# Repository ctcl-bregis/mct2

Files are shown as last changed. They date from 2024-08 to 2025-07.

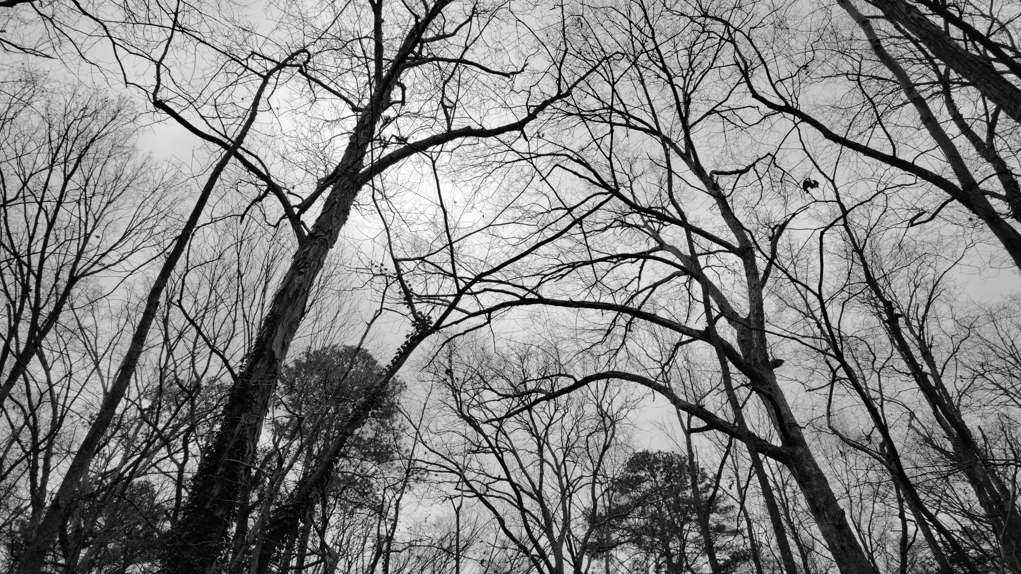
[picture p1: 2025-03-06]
media/background/mct2_midlo_1_1080p.png

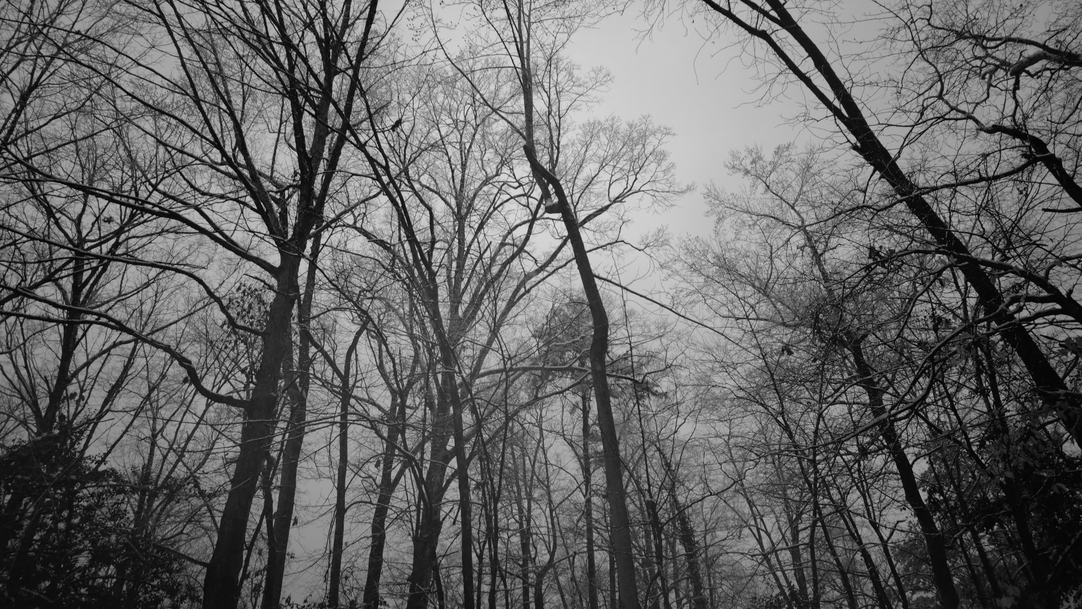
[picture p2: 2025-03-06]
media/background/mct2_midlo_1_v2_1080p.png

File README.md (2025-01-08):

<div>
  MediaCow Touch 2
</div>

# MediaCow Touch 2
MediaCow Touch 2 "Paris" is the successor to MediaCow Touch (1) "Nashville" which is a DIY portable tablet computer.

This repository has all of the hardware designs and some software for the project.

See [MediaCow Touch 2 page](https://ctcl.lgbt/projects/mct2/) for more information.

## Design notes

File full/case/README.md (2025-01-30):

This directory is to have design files for the case using the DFRobot 11.6 Inch 1920x1080 FHD eDP Touch Display (FIT0955)

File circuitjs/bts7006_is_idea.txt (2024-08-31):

$ 1 0.000005 10.20027730826997 50 5 50 5e-11
r 880 480 880 560 0 1200
g 880 560 880 576 0 0
R 848 400 848 304 0 0 40 20 0 0 0.5
r 608 480 608 560 0 100000
g 608 560 608 576 0 0
r 784 480 880 480 0 470000
c 688 480 688 560 0 2.2e-10 3.3878214977944507 0
g 688 560 688 576 0 0
b 309 415 658 869 0
b 808 293 949 456 0
w 688 480 608 480 0
x 311 408 338 411 4 12 MCU
x 807 285 891 288 4 12 BTS7006-1EPP
167 448 480 480 480 1024 12
w 608 480 544 480 0
R 544 832 592 832 0 0 40 3.3 0 0 0.5
419 320 480 416 480 1024 12
O 688 480 688 416 1 0
34 MMSZ5227B 0 1.0000000000000001e-7 24 11.402862559935903 3.6 0.1
z 784 560 784 480 2 MMSZ5227B
g 784 560 784 576 0 0
x 809 508 826 511 4 24 R
x 826 513 851 516 4 12 ADC
x 891 548 908 551 4 24 R
x 908 553 948 556 4 12 SENSE
x 309 352 355 355 4 24 Idea
w 784 480 688 480 0
i 912 336 912 400 0 0.045
g 912 336 912 320 0 0
S 880 480 880 400 0 0 false 0 2
w 896 400 912 400 0
w 864 400 848 400 0
o 3 128 0 4099 20 0.0001953125 0 2 3 3
o 0 128 0 4099 160 0.1 1 2 0 3
38 2 F1 0 0 48 -1 Voltage
38 26 F1 0 0 0.045 -1 Current

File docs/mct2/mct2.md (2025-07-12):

**Disclaimer**: Anything on this page and other pages related to this project is preliminary data and may change at any moment. Much of the following pages are a work in progress and may be incomplete.

## Overview
MediaCow Touch 2 is a tablet computer project that focuses on security, privacy, transparency and repairability. The project started in March 2021 while active development stared in June 2024.

In March 2025, development of a variant, MediaCow Touch 2 Lite, started in order to have a version of the project that can be completed in a shorter time frame.

### Specifications

Specifications for MediaCow Touch 2 "Paris" and MediaCow Touch 2 Lite "Curitiba" are listed below.

| Specification | MediaCow Touch 2 "Paris"  | MediaCow Touch 2 Lite "Curitiba"  |
| --- | --- | --- |
| SoC | Intel N100/N305 | Intel N100 |
| Memoryy | 8GB-16GB LPDDR5 | 8GB LPDDR5 |
| Storage | Configurable | Configurable |
| Display | 14" 1920x1200 Innolux AAS | 14" 1920x1200 Innolux AAS |
| Camera | TBD | TBD |
| Audio | TBD | IDT 92HD95 HD Audio CODEC |
| Embedded Controller | Sunplus/Tibbo SP7021 | STMicroelctronics STM32L071V8Tx |
| Battery | TBD | TBD |
| Dimensions | TBD | TBD |
| Weight | TBD | TBD |

## Naming
In 2025, MediaCow Touch 2 was split into two projects: MediaCow Touch 2 and MediaCow Touch 2 Lite. 

MediaCow Touch 2 "Paris" is refered to as the "Full" version and has all of the features introduced during development in 2024 including the SP7021 as the embedded controller, the side-mounted display and modular connectors.

MediaCow Touch 2 Lite "Curitiba" is the version of the project introduced in 2025 that leaves out many features to decrease development time and cost.

## Documentation
The pages are currently under a rewrite due to the introduction of MediaCow Touch 2 Lite so much of it is currently unavailable.

The following link to specific parts of the documentation:

{{button|page=/projects/mct2/connectivity/}}
{{button|page=/projects/mct2/display/}}
{{button|page=/projects/mct2/pcb/}}

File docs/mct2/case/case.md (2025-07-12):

## Material and Fabrication
MediaCow Touch 2's case is to be constructed from white PET(G) plastic as part of the theme.

Fortunately, the case's parts can be 3D printed whole as the total dimensions are within the 350x350mm bounds of a 3D printer available at a local makerspace.

## Design
The case is designed in OpenSCAD.

The case is split into three parts: the base, the display mount and the display cover. These parts are bolted together at four to six points. 

## Parts
The case is to be split into three parts: the **base**, the **display mount** and the **display cover**.

### Display Mount
The display mount is a tray-like structure that holds the display in place. The structure is made up of a single rectangle that is surrounded by walls.

The display mount was inspired by the System Cover Design Guidance section of the Innolux N156HGE and N140JCN-GS9 datasheet and various laptops that use a similar design such as the ThinkPad X240.

The display is held in place using double-sided tape that also acts as a spacer as the thickness of the display is wider at the LCD driver PCB area.

### Display Cover
The display cover is a thin layer that covers the outside edges of the display, acting as a screen bezel. 

### Base
The base component consists of the walls, PCB mounting points, connector cutouts and mounting points for connectors. It defines the structure of the device.

#### Side-mounted display mount
**Not present on MediaCow Touch 2 Lite**

The small touchscreen display on the side of the case is to be attached to the Side-Mounted Display PCB that contains the FPGA-based RGB-MIPI video bridge. The PCB is to be bolted at two or more points to mounting posts.

#### Keypad
**Not present on MediaCow Touch 2 Lite**

The keypad board, providing twelve tactile button switches. 

#### Buttons
**Only present on MediaCow Touch 2 Lite**

On MediaCow Touch 2 Lite, the buttons are to be mounted on the PCB with cutouts in the the case for the button caps.

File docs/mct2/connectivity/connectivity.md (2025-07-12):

## Physical Connectivity

MediaCow Touch 2 has the following physical connectivity:
- 2x USB Type-C with Power Delivery sink/source up to 20v, DP alternate mode and USB 3.2
- 2x USB 3.2 Type-A
- 1x RJ-45 Ethernet, provided by internal M.2 module
- 1x Full-size HDMI
- 1x 3.5mm headphone audio out
- 1x 3.5mm microphone audio in

MediaCow Touch 2 Lite has the following physical connectivity:
- 2x USB Type-C with Power Delivery sink/source up to 20v, DP alternate mode and USB 3.2
- 2x USB 3.2 Type-A
- 1x Full-size HDMI
- 1x 3.5mm headphone audio out
- 1x 3.5mm microphone audio in

### Audio

#### MediaCow Touch 2 "Paris"
**TBD**

#### MediaCow Touch 2 Lite "Curitiba"
MediaCow Touch 2 Lite "Curitiba" uses an HD Audio CODEC, making use of the HD Audio interface directly. Currently, the CODEC being used is the Tempo 92HD95. 

## Internal Connectivity
**TODO**: move all of this to PCB design pages

### TCP Ports
On MediaCow Touch 2 and MediaCow Touch 2 Lite, both TCP ports are used for USB Type-C providing USB 3.2, Power Delivery up to 20v and DisplayPort alternate mode.

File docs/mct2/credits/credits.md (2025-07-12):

## Software Used
Open Source software has been used whenever possible. 

### CAD and EDA

#### KiCAD
KiCAD is used to draw electrical schematics and design the carrier board PCB.

#### LibreCAD
LibreCAD was used for the first time on August 6 to record measurements of the battery pack that is used in the device.

Its use, however, was brief and was eventually replaced by QCAD.

#### QCAD
Starting January 1, 2025, QCAD is used for technical, mechanical drawings, taking place of draw.io for such task. Its use is still limited.

#### OpenSCAD 
OpenSCAD is used extensively for 3D design.

#### FreeCAD
FreeCAD was very briefly used for case design. No part of the current case design was done in FreeCAD.

### Planning and Documentation

#### draw.io/diagrams.net
draw.io is extensively used for rough physical diagrams and electrical block diagrams. The draw.io desktop client command line features are used by StaticSite to render .drawio files.

#### Git and GitHub
The MediaCow Touch 2 hardware design and software files are hosted on GitHub for anyone to see while having the ability to easily sync progress across devices in cases where I have to go somewhere.

#### StaticSite
StaticSite is used to generate this website starting December 31, 2024. Prior to this, website backends called "ctclsite-rust" and "ctclsite-python" were used to serve website content.

#### Discord
Using a chat service in as a way to dump ideas into categories has returned from MediaCow Touch 1 where I used a self-hosted Rocket.Chat instance for that purpose. This time I used a private "server" on Discord to brainstorm ideas. At the conclusion of the project, I would make a public release of the channel logs. 

#### MediaWiki
A self-hosted MediaWiki instance is used for personal documentation. It's role in MediaCow Touch 2, however, is very limited. 

#### STM32CubeMX
STM32CubeMX was used to select the microcontroller used as the embedded controller (SMEC) and plan its pinout until the switch to the SP7021 as the embedded controller.

#### Sourcegraph Cody + Claude 3.5/Claude 3.7/GPT-4o
Sourcegraph Cody has found extensive use in many of my projects, including this one, starting in late 2024. It is used for sentence completion in documentation and code completion in software and firmware development. Some case design with OpenSCAD was assisted by AI.

#### CircuitJS
[CircuitJS](https://falstad.com/circuit/) has been used to test ideas such as using Schottky diodes on the power inputs of SPI flash memory and connecting the IS pin of the Infineon BTS7006 to a microcontroller.

### Software Development
This software was used to develop software for the project.

#### VSCodium
VSCodium is used as the main editor for any software project, including this website. Content like these pages are written using VSCodium.

The 'Open Remote - SSH' extension played a crucial role during development as it let me edit files on the desktop PC from anywhwere like I am using VSCodium on that system.

## Hardware Used
Hardware used for development since May 2024:

**Format: Codename - Motherboard**

### Development Hardware

- LattePanda Mu N100
  - Experimentation
  - Communications
  - Research

### Workstations

- ASRock B550M Pro4
  - Circuit and device design
  - Documentation
  - Software development
  - Research
  - Communications
- HP ZBook Studio G3 15
  - Circuit and device design
  - Documentation
  - Software development
  - Research
  - Communications
- Lenovo ThinkPad T450s
  - Device design
  - Documentation
  - Research
- Lenovo ThinkPad T430s
  - Communications
  - Circuit design
  - Documentation
  - Research
  - Planning
- Apple iPhone XR (A1984)
  - Social media promotion
  - Research
  - Communications
- ASUS Zenfone 9 (AI2202)
  - Documentation
  - Communications
  - Research
  - Remote internet access
- Valve Steam Deck OLED (1030)
  - Communications
  - Documentation
  - Research
  - Planning
- Samsung Galaxy S7 WW (SM-G930F)
  - Communications
  - Research
  - Planning
- MediaCow Touch 1 (Banana Pi BPI-M64)
  - Communications
  - Media playback

Non-CTCL Hardware:
- Dell OptiPlex 7460 AIO - Brightpoint Community College MIDLRTC19928
  - Datasheet viewing

### Servers

- SVCS1 (pre-2025) - HP ProLiant BL460c G8
  - File storage host (Nextcloud)
  - Planning (MediaWiki)
  - DNS server
- SVCS1 (2025) - Supermicro X8DAi
  - DNS server
- WBSD1 - Supermicro X8SIE
  - File storage
- ROUTER1 - Supermicro X8SIE
  - Router
  - Remote access host

### Other

- Texas Instruments TI-Nspire CX
  - Formula calculation
- Flipper Zero FZ.1
  - Device debugging

## Locations

MediaCow Touch 2 was developed in the following locations:

- Atlantic Beach, North Carolina, United States
- Bramwell, West Virginia, United States
- Doswell, Virginia, United States
  - Kings Dominion
- Fort Myers Beach, Florida, United States
- Fort Myers, Florida, United States
- Midlothian, Virginia, United States
  - Brightpoint Community College Midlothian Campus
  - Clover Hill Public Library
  - Midlothian Library
- Orlando, Florida, United States
- Pocahontas, West Virginia, United States
- Richmond, Virginia, United States
  - Build, RVA
  - Maymont Estate
  - VCU Engineering East Hall Qimonda Atrium
  - The Pace Center (VCU)
- Verona Beach, New York, United States
- Canastota, New York, United States
- Cazenovia, New York, United States

Most development was done in Midlothian, Virginia.

This list excludes any work done from aircraft, which was an Airbus A320 for both the departing and return flights from Orlando, Florida during the August 2024 trip to the Fort Myers Beach area.

## Individuals and Organizations
This project was made possible by LattePanda where hardware and documentation was provided.

### Hardware
These organizations and individuals have provided hardware for me to use for development.

- Banana Pi - MediaCow Touch 2 Full 
- Chesterfield Auto Parts
- CrashSys (OEW; One-Eyed Willie)
- LattePanda
- Shenzhen Graperain Technology - 2022 Designs
- Tailorpixels - MediaCow Touch 2 Full

### Direct Technical Support
These organizations and individuals have provided direct technical support for development through email, chat and other means:

Individuals:
- Arya
  - eDP adapter board revision in April 2025

Organizations:
- Adafruit
  - Community support over Discord for battery management ideas
- GOWIN
  - Email support about MIPI DPHY capabilities, before switching to a Lattice FPGA for the RGB-MIPI bridge
- LattePanda
  - Support for hardware and software development over email and Discord
- Shenzhen Graperain Technology
  - 2022 RK3399-based design: email support and development files
- Tailorpixels
  - Tech support over email
- Tibbo Technology
  - Email support for receiving more information about the SP7021

### Technical Support
Organizations that provided guides, datasheets and other technical support documents that were used in development:

- Adafruit
- Advantech
- Altium
- Analog Devices (including Linear Technology Corporation and Maxim Integrated)
- Congatec
- Crystalfontz
- CTS
- Delta Electronics
- Dialog Semiconductor (including Silego)
- Diodes Incorporated
- ECS
- Flipper Devices
- Foxconn
- Framework Computer
- Fuzhou Rockchip
- GOWIN
- Hirose
- Infineon Technologies (including Cypress Technology and Qimonda)
- Innolux Display
- Intel
- ISSI
- JST
- Kinetic Technologies
- KIOXIA
- LOTES
- Lumissil
- MacroSilicon
- MediaTek
- Micron Technology
- Molex
- Monolithic Power Systems
- Nanya Technology
- Nexperia
- NXP
- Onsemi
- Raydium Corp.
- Renesas (including Intersil)
- Richtek
- Rohm
- Samsung Electro-Mechanics
- Samsung Electronics
- Samsung Semiconductor
- Shenzhen Graperain Technology
- Silergy
- SINOVOIP Banana Pi
- Sunplus Technology
- SiTime
- STMicroelectronics
- Super Micro Computer (hereinafter refered to as Supermicro)
- Tailorpixels
- Tempo Semiconductor (including IDT and SigmaTel)
- Texas Instruments
- Tibbo Technology
- Toradex
- Toshiba
- Valve Corporation
- Vishay (including Siliconix and General Semiconductor)
- Winbond Electronics
- Xi'an Aerosemi Technology
- YAGEO

## Inspiration
MediaCow Touch 2 takes inspiration from existing devices and media.

### Device Design
MediaCow Touch 2's design and hardware had inspiration from the following products:

- Ainol NOVO7 Paladin
  - Display mount ideas
- Apple MacBook various models from 2019 to 2022 with Touch Bar
  - Side-mounted display idea
- Apple iPhone 6S
  - Display selection
- Apple iPhone XR
  - Display selection
- ASUS Chromebook Flip C100P
  - Some inspiration for original Rockchip-based MediaCow Touch 2 idea (2021-2022)
  - Display selection
  - Embedded controller ideas
  - Battery management ideas
- ASUS Zenfone 9 AI2202
  - USB Type-C feature inspiration, specifically USB PD capabilities
- Banana Pi BPI-F2P/BPI-F2S
  - Circuit design reference
- Dell Latitude D630
  - Audio CODEC IC selection
- Flipper Devices Flipper Zero FZ.1
  - LED controller ideas
  - **MediaCow Touch 2 Full**: Original inspiration for SMEC's side-mounted display
- Framework Laptop 13 (11th Gen Intel)
  - USB Type-C feature and IC selection
  - Circuit design reference
- HP ZBook Studio G3 15
  - USB Type-C feature inspiration
  - Display selection
  - CPU cooling ideas
  - M.2 mount ideas
  - Some influence in choosing the audio CODEC IC
- HP(E) ProLiant BL460c G8, BladeSystem C3000 chassis, ProLiant DL380 G7
  - Inlet temperature sensor idea
- HP(E) BladeSytem C3000 chassis
  - **MediaCow Touch 2 Full**: Possible inspiration for SMEC
- LattePanda Mu Full Carrier
  - Circuit design reference
- LattePanda Mu Lite Carrier
  - Circuit design reference
- Lenovo 100e Chromebook 2nd Gen (11.6" Intel)
  - Status LED idea
  - USB Type-C feature ideas
- Lenovo ThinkPad T430s
  - Battery layout ideas
- Lenovo ThinkPad T450s
  - Battery layout ideas
- Lenovo ThinkPad X240
  - Display mount ideas
- Matterport Pro2
  - Battery layout ideas
  - CPU cooling ideas
- Microsoft Surface series
  - Overall physical design inspiration
- Microsoft Zune series
  - Original inspiration for MediaCow
- Nintendo Switch (2017)
  - Display selection
  - USB Type-C Power Delivery ideas
- Positivo BGH Y210
  - Camera placement idea
- Samsung Chromebook XE500C13
  - Display size comparison
  - Status LED idea
  - **MediaCow Touch 2 Lite**: passive cooling idea
  - **MediaCow Touch 2 Lite**: port selection
- Samsung Galaxy S7 SM-G930F
  - Status LED idea
  - Display selection
  - Camera ideas
- Samsung Galaxy Tab3 10.1 P5210
  - Used as an example of an x86-based tablet
- Supermicro H13SAE-MF
  - Socketed BIOS idea
  - TPM module pinout
- Valve Steam Deck LCD (1010) and OLED (1030)
  - Overall physical design inspiration
  - Device usage ideas
  - Component selection

### Media Inspirations

- OneShot (2016 game), OneShot World Machine Edition (2022/2024 game)
  - Major aesthetic inspiration
  - Use of Terminus for UI fonts and in documentation
  - Display video switch PCB idea being named "Solstice"
  - Clover symbol on PCB designs
- ULTRAKILL (2018-present game)
  - Use of VCR OSD Mono for UI fonts
  - reference in side-mounted display example code
- OK K.O. Let's Be Heroes (2017-2019 series)
  - Addition of "Cool S" symbol to all PCB designs for projects since MathPad (2022)
- Steven Universe (2013-2019 series), 2017 episode specifically
  - Idea of the addition of a strap to the device

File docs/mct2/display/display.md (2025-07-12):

Choosing the display used in MediaCow Touch 2 was one of the first research efforts in the project during the 2024 development period.

## Display Selection
I prefer AAS (Azimuthal Anchoring Switch) IPS technology that is specific to Innolux panels.

At first, after weeks of research, I decided to use the 11.6" touchscreen from DFRobot as it is intended for use with LattePanda systems, including the Mu. It was also the lowest cost option for a display of its size and resolution.

Late in 2024, I found out that laptop displays with integrated touchscreens can be found inexpensively though often they are 13.3" or larger. Though I am already reaching the limit of what could be printed on 3D printers available to me, I may be able to use panels up to 14".

On February 15, 2025, I decided to use the Innolux N140JCN-GS9 over the DFRobot FIT0955 display and the case design was updated to reflect this. This has the device very close to the 350mm x 350mm limit of the 3D printer currently available at a local makerspace; Build, RVA. 

## Display Adapter PCB
A display adapter PCB was designed to convert the 40-pin, 4-lane eDP connector of the LattePanda Mu to the 40-pin, 2-lane + touchscreen eDP connector of the N140JCN-GS9.

I left a separate connector for USB data since the connector has pins for both I2C and USB, left reserved if the specific bus is not used. For example, on the N140JCN-GS9 specifically does not have so the USB pins are left unused.

The USB and I2C connectors on the adapter PCB should not be both connected at the same time.

*TODO: list pinout here*

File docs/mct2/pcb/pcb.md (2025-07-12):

This page and subpages cover the PCB design of MediaCow Touch 2 and MediaCow Touch 2 Lite.

## Subpages

{{button|page=/projects/mct2/pcb/lite/}}
{{button|page=/projects/mct2/pcb/full/}}

## Notes
These notes apply to both MediaCow Touch 2 "Paris" and MediaCow Touch 2 Lite "Curitiba".

### Infineon MOSFETs
For Infineon transistors using TDSON-8 and TSDSON-8, the following pins are assigned to the pins on the KiCAD symbol and footprint:

| Chip pin | KiCAD pin | Purpose |
| --- | --- | --- |
| 1, 2, 3 | 1 | Source  |
| 4 | 2 | Gate |
| 5, 6, 7, 8 | 3 | Drain |

Though these devices technically have eight pins, in the schematic, they have three pins.

### Use of MEMS oscillators
Even in larger packages, helium could still seep into the package of MEMS oscillator over time, reducing reliability in environments where there is a high concentration of helium.

Since the benefit of using a MEMS oscillator on MediaCow Touch 2 is near non-existant, where size and battery is plentiful, a quartz oscillator is to be used instead for SMEC (STM32/SP7021).

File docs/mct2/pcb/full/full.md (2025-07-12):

This document is here to move stuff from Connectivity and should be cleaned up if "Paris" is ever to be developed.

### HSIO

| Port | Purpose | PCIe Device | PCIe Controller |
| --- | --- | --- | --- |
| HSIO 0  | Ext. USB 3  | N/A | Controller #1 |
| HSIO 1  | Ext. USB 3  | N/A | Controller #1 |
| HSIO 2  | M.2 Key E | 1 | Controller #1 |
| HSIO 3  | M.2 Key B | 2 | Controller #1 |
| HSIO 6  | M.2 Key A/E | 3 | Controller #2 |
| HSIO 8  | M.2 Key M | 4 | Controller #3 |
| HSIO 9  | M.2 Key M | 4 | Controller #3 |
| HSIO 10 | M.2 Key M | 4 | Controller #3 |
| HSIO 11 | M.2 Key M | 4 | Controller #3 |

- The first two HSIO lanes are used as USB 3.2 connected to the two USB Type-C ports. 
- The M.2 Key E slot is intended for use with a Wi-Fi/BT module, with USB 2.0 provided alongside a PCIe lane.
- The M.2 Key B slot is intended for use with a 5G/LTE module, with USB 2.0 provided alongside a PCIe lane. A SIM card slot may be present on the carrier board.
- The M.2 Key A/E slot is intended for use with a M.2 Ethernet module.
- The M.2 Key M slots are intended for use with a M.2 NVMe SSD. This slot could also be used for a M.2 SATA module and ATA power connectors may be provided on the carrier board for this purpose.

### SOM_USB2_
The LattePanda Mu SoM exposes eight USB 2.0 interfaces.

Since USB2 interfaces 1, 2, 5 and 6 are able to be assigned to USB Type-C (TCP) ports, 5 and 6 are used for the USB Type-C ports on both versions of MediaCow Touch 2.

Since USB 3.0 connectors have both USB 2 and USB 3 links, USB 2.0 interfaces 1 and 2 are used for the USB 3.2 Type-A ports on both versions of MediaCow Touch 2.

MediaCow Touch 2 "Paris" uses all of the USB 2.0 interfaces.

| Port | Purpose |
| --- | --- |
| USB2_P1 | Ext. USB 3  |
| USB2_P2 | Ext. USB 3  |
| USB2_P3 | M.2 Key E |
| USB2_P4 | M.2 Key B |
| USB2_P5 | TCP Port 1  |
| USB2_P6 | TCP Port 2  |
| USB2_P7 | Webcam |
| USB2_P8 | SMEC HID |

Along with I2C and QSPI, a USB 2.0 link is also included between the SoM and SMEC (SP7021). The USB 2.0 link may be used to emulate a keyboard device.

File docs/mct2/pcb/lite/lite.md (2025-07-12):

## Block Diagram

Simplified block diagram

## Net List

### AC_AVDD
### AC_DMIC_CLK
### AC_DMIC_D0
### AC_DMIC_D1
### AC_DVDD
### AC_EAPD
### AC_PCBEEP
### AC_PORTA_L
### AC_PORTA_R
### AC_PORTB_L
### AC_PORTB_R
### AC_PORTB_VREF
### AC_PORTC_L
### AC_PORTC_R
### AC_PORTC_VREF
### AC_PORTD_LN
### AC_PORTD_LP
### AC_PORTD_RN
### AC_PORTD_RP
### AC_SENSE_A

## BM_ - Battery Management

### BM_1V05
1.05v supply used as a PROCHOT pull-up reference.

It is supplied by a switching regulator-LDO combination.

### BM_CHRGOK
Charge status output from the BQ25723

### BM_CMPOUT

### BM_OTG_VAP_FRS
### BM_REGN
### BM_VDDA
### EC_BM_I2C_SCL
### EC_BM_I2C_SDA
### EC_IOVDD
### EC_PM_I2C_ALT
### EC_PM_I2C_SCL
### EC_PM_I2C_SDA

## HDMI_ - HDMI Output Connector

### HDMI_5V
### HDMI_5V_CN
### HDMI_AUX_N
### HDMI_AUX_P
### HDMI_CEC
### HDMI_CLKN
### HDMI_CLKP
### HDMI_CLK_N
### HDMI_CLK_P
### HDMI_CN_CEC
### HDMI_CN_HPD
### HDMI_CN_SCL
### HDMI_CN_SDA
### HDMI_CT_HPD
### HDMI_D0N
### HDMI_D0P
### HDMI_D1N
### HDMI_D1P
### HDMI_D2N
### HDMI_D2P
### HDMI_HPD
### HDMI_LS_OE
### HDMI_SCL
### HDMI_SDA
### HDMI_TX0_N
### HDMI_TX0_P
### HDMI_TX1_N
### HDMI_TX1_P
### HDMI_TX2_N
### HDMI_TX2_P
### HDMI_UTILITY
### HDMI_VCCA

## LED_ - Charge Port RGB Status LED

### LED_3V3
### LED_EN
### LED_VBM

## M2E_ - M.2 Key E Connector

### M2E_COEX1
### M2E_COEX2
### M2E_COEX3
### M2E_I2C_ALT
### M2E_I2S_CLK
### M2E_I2S_SDIN
### M2E_I2S_SDOUT
### M2E_I2S_WS
### M2E_LED1
### M2E_LED2
### M2E_PCIE_CLKREQ
### M2E_PCIE_RST
### M2E_PCIE_RX_N
### M2E_PCIE_RX_P
### M2E_PCIE_TX_N
### M2E_PCIE_TX_P
### M2E_PCIE_WAKE
### M2E_POWER_SNK
### M2E_POWER_SRC
### M2E_SDIO_CLK
**Unused on MediaCow Touch 2 Lite "Curitiba"** as the LattePanda Mu does not have an SDIO interface.

### M2E_SDIO_CMD
**Unused on MediaCow Touch 2 Lite "Curitiba"** as the LattePanda Mu does not have an SDIO interface.

### M2E_SDIO_DATA0
**Unused on MediaCow Touch 2 Lite "Curitiba"** as the LattePanda Mu does not have an SDIO interface.

### M2E_SDIO_DATA1
**Unused on MediaCow Touch 2 Lite "Curitiba"** as the LattePanda Mu does not have an SDIO interface.

### M2E_SDIO_DATA2
**Unused on MediaCow Touch 2 Lite "Curitiba"** as the LattePanda Mu does not have an SDIO interface.

### M2E_SDIO_DATA3
**Unused on MediaCow Touch 2 Lite "Curitiba"** as the LattePanda Mu does not have an SDIO interface.

### M2E_SDIO_RST
**Unused on MediaCow Touch 2 Lite "Curitiba"** as the LattePanda Mu does not have an SDIO interface.

### M2E_SDIO_WAKE
**Unused on MediaCow Touch 2 Lite "Curitiba"** as the LattePanda Mu does not have an SDIO interface.

### M2E_UART_CTS
### M2E_UART_RTS
### M2E_UART_RX
### M2E_UART_TX
### M2E_UART_WAKE
### M2E_UIM_SWP
### M2E_USB_DN
### M2E_USB_DP
### M2E_VD1
May be **Unused on MediaCow Touch 2 Lite "Curitiba"**

### M2E_VD2
May be **Unused on MediaCow Touch 2 Lite "Curitiba"**

### M2E_VD3
May be **Unused on MediaCow Touch 2 Lite "Curitiba"**

### M2E_WDISABLE1
Wireless disable signal, driven by SMEC

### M2E_WDISABLE2
Wireless disable signal, driven by SMEC

## SOM_ - System On Module (LattePanda Mu) Connections

### SOM_CSI_C_CLK_N/SOM_CSI_C_CLK_P
**Unused on MediaCow Touch 2 Lite "Curitiba"**.
CSI Port C Clock differential pair input for the CSI Camera.

### SOM_CSI_C_D0_N/SOM_CSI_C_D0_P
**Unused on MediaCow Touch 2 Lite "Curitiba"**.
CSI Port C Data differential pair lane 0.

### SOM_CSI_C_D1_N/SOM_CSI_C_D1_P
**Unused on MediaCow Touch 2 Lite "Curitiba"**.
CSI Port C Data differential pair lane 1.

### SOM_CSI_D_CLK_N/SOM_CSI_D_CLK_P
**Unused on MediaCow Touch 2 Lite "Curitiba"**.
CSI Port D Clock differential pair input for the CSI Camera.

### SOM_CSI_D_D0_N{slash}C_D3_N / SOM_CSI_D_D0_P{slash}C_D3_P
CSI Port D Data differential pair lane 0 **or** CSI Port C Data differential pair lane 3. **Unused on MediaCow Touch 2 Lite "Curitiba"**.

### SOM_CSI_D_D1_N{slash}C_D2_N / SOM_CSI_D_D1_P{slash}C_D2_P
CSI Port D Data differential pair lane 1 **or** CSI Port C Data differential pair lane 2. **Unused on MediaCow Touch 2 Lite "Curitiba"**.

### SOM_FAN1_PWM
**Unused on MediaCow Touch 2 Lite "Curitiba"** as no fans are used.
Super IO Fan 1 PWM output.

### SOM_FAN1_TAC
**Unused on MediaCow Touch 2 Lite "Curitiba"** as no fans are used.
Super IO Fan 1 Tachometer input.

### SOM_FAN2_PWM
**Unused on MediaCow Touch 2 Lite "Curitiba"** as no fans are used.
Super IO Fan 2 PWM output.

### SOM_FAN2_TAC
**Unused on MediaCow Touch 2 Lite "Curitiba"** as no fans are used.
Super IO Fan 2 Tachometer input.

### SOM_GSX_CLK
### SOM_GSX_DIN
### SOM_GSX_DOUT
### SOM_GSX_RESET
### SOM_GSX_SLOAD
### SOM_HDA_BCLK
### SOM_HDA_RST
### SOM_HDA_SDIN
### SOM_HDA_SDOUT
### SOM_HDA_SYNC

### SOM_HSIO_
The HSIO connections on the Intel N100/N305 are mostly used for providing PCIe lanes with the only two being used for other purposes are HSIO0 and HSIO1.

| Port | Purpose | PCIe Device | PCIe Controller |
| --- | --- | --- | --- |
| HSIO 0  | Ext. USB 3  | N/A | Controller #1 |
| HSIO 1  | Ext. USB 3  | N/A | Controller #1 |
| HSIO 2  | Reserved | N/A | Controller #1 |
| HSIO 3  | Reserved | N/A | Controller #1 |
| HSIO 6  | M.2 Key E | 1 | Controller #2 |
| HSIO 8  | M.2 Key M | 2 | Controller #3 |
| HSIO 9  | M.2 Key M | 2 | Controller #3 |
| HSIO 10 | M.2 Key M | 2 | Controller #3 |
| HSIO 11 | M.2 Key M | 2 | Controller #3 |

- The first two HSIO lanes are used as USB 3.2 connected to the two USB Type-C ports. 
- The M.2 Key E slot is intended for use with a Wi-Fi/BT module, with USB 2.0 provided alongside a PCIe lane.
- The M.2 Key M slots are intended for use with a M.2 NVMe storage module. This slot could also be used for a M.2 SATA module.

#### SOM_HSIO0_RX_N
#### SOM_HSIO0_RX_P
#### SOM_HSIO0_TX_N
#### SOM_HSIO0_TX_P
#### SOM_HSIO1_RX_N
#### SOM_HSIO1_RX_P
#### SOM_HSIO1_TX_N
#### SOM_HSIO1_TX_P
#### SOM_HSIO2_RX_N
#### SOM_HSIO2_RX_P
#### SOM_HSIO2_TX_N
#### SOM_HSIO2_TX_P
#### SOM_HSIO3_RX_N
#### SOM_HSIO3_RX_P
#### SOM_HSIO3_TX_N
#### SOM_HSIO3_TX_P
#### SOM_HSIO6_RX_N
#### SOM_HSIO6_RX_P
#### SOM_HSIO6_TX_N
#### SOM_HSIO6_TX_P
#### SOM_HSIO8_RX_N
#### SOM_HSIO8_RX_P
#### SOM_HSIO8_TX_N
#### SOM_HSIO8_TX_P
#### SOM_HSIO9_RX_N
#### SOM_HSIO9_RX_P
#### SOM_HSIO9_TX_N
#### SOM_HSIO9_TX_P
#### SOM_HSIO10_RX_N
#### SOM_HSIO10_RX_P
#### SOM_HSIO10_TX_N
#### SOM_HSIO10_TX_P
#### SOM_HSIO11_RX_N
#### SOM_HSIO11_RX_P
#### SOM_HSIO11_TX_N
#### SOM_HSIO11_TX_P
### SOM_I2C2_SCL
### SOM_I2C2_SDA
### SOM_I2C3_SCL
### SOM_I2C3_SDA
### SOM_I2C4_SCL
### SOM_I2C4_SDA
### SOM_I2C5_SCL
### SOM_I2C5_SDA
### SOM_I2S_MCLK
### SOM_I2S_RXD
### SOM_I2S_SCLK
### SOM_I2S_SFRM
### SOM_I2S_TXD
### SOM_PCIE_CLKREQ3
### SOM_PCIE_CLKREQ4
### SOM_PCIE_PLTRST
### SOM_PCIE_REF0_N
### SOM_PCIE_REF0_P
### SOM_PCIE_REF1_N
### SOM_PCIE_REF1_P
### SOM_PCIE_REF2_N
### SOM_PCIE_REF2_P
### SOM_PCIE_REF3_N
### SOM_PCIE_REF3_P
### SOM_PCIE_REF4_N
### SOM_PCIE_REF4_P
### SOM_PCIE_WAKE
### SOM_PROCHOT
### SOM_PWRBTN
### SOM_RSTBTN
### SOM_RTC_BAT
### SOM_SATAXPCIE0
### SOM_SATAXPCIE1
### SOM_SBK0
### SOM_SBK1
### SOM_SBK2
### SOM_SBK3
### SOM_SIO_SLS_S0
### SOM_SIO_SLS_S3

### SOM_SIO_UART - System UART output
Supposedly these pins are used for system UART console output.

#### SOM_SIO_UART_RX
#### SOM_SIO_UART_TX

### SOM_SMB_ALT
### SOM_SMB_SCL
### SOM_SMB_SDA

### SOM_SML_ - Intel SMLink connections

#### SOM_SML_ALT
#### SOM_SML_PMCALT
#### SOM_SML_SCL
#### SOM_SML_SDA

### SOM_SPI_ - SPI connections
This SPI connection is used for both external BIOS flash and TPM.

#### SOM_SPI_BIOS_SEL
Switch to select on-module BIOS flash or on-board BIOS flash.

May be connected to a PCB jumper or DIP switch to assert high or low.

#### SOM_SPI_CLK
SPI clock output

#### SOM_SPI_CS
SPI chip select output for BIOS flash.

#### SOM_SPI_CS2
SPI chip select output for TPM.

#### SOM_SPI_IO0_MOSI
SPI data output from SoM or QSPI Data 0.

#### SOM_SPI_IO1_MISO
SPI data input to SoM or QSPI Data 1.

#### SOM_SPI_IO2
QSPI Data 2 from or to SoM.

#### SOM_SPI_IO3
QSPI Data 3 from or to SoM.

#### SOM_SPI_TPM_IRQ
SPI interrupt from TPM.

#### SOM_SPI_VCC
Dedicated 3.3v for BIOS flash and TPM.

### SOM_SPKR_SATALED
### SOM_SUSCLK
### SOM_TSENSE
### SOM_UART0_RX
### SOM_UART0_TX
### SOM_UART1_RX
### SOM_UART1_TX
### SOM_UART2_RX
### SOM_UART2_TX

#### SOM_USB2_
The LattePanda Mu SoM exposes eight USB 2.0 interfaces.

Since USB2 interfaces 1, 2, 5 and 6 are able to be assigned to USB Type-C (TCP) ports, 5 and 6 are used for the USB Type-C ports on both versions of MediaCow Touch 2.

Since USB 3.0 connectors have both USB 2 and USB 3 links, USB 2.0 interfaces 1 and 2 are used for the USB 3.2 Type-A ports on both versions of MediaCow Touch 2.

| Port | Purpose |
| --- | --- |
| USB2_P1 | Ext. USB 3  |
| USB2_P2 | Ext. USB 3  |
| USB2_P3 | |
| USB2_P4 | |
| USB2_P5 | TCP Port 1  |
| USB2_P6 | TCP Port 2  |
| USB2_P7 | |
| USB2_P8 | |

#### SOM_USB2_P1_N
#### SOM_USB2_P1_P
#### SOM_USB2_P2_N
#### SOM_USB2_P2_P
#### SOM_USB2_P3_N
#### SOM_USB2_P3_P
#### SOM_USB2_P4_N
#### SOM_USB2_P4_P
#### SOM_USB2_P5_N
#### SOM_USB2_P5_P
#### SOM_USB2_P6_N
#### SOM_USB2_P6_P
#### SOM_USB2_P7_N
#### SOM_USB2_P7_P
#### SOM_USB2_P8_N
#### SOM_USB2_P8_P
### SOM_USB_OC
### SOM_VSYS

## USB Type C

### TCP0_AUX_N
### TCP0_AUX_P
### TCP0_CC1
### TCP0_CC1_CN
### TCP0_CC2
### TCP0_CC2_CN
### TCP0_DN
### TCP0_DP
### TCP0_HPD
### TCP0_PPHV
### TCP0_PPHV_EN
### TCP0_SBU1
### TCP0_SBU1_CN
### TCP0_SBU2
### TCP0_SBU2_CN
### TCP0_TX0_N
### TCP0_TX0_P
### TCP0_TX1_N
### TCP0_TX1_P
### TCP0_TXRX0_N
### TCP0_TXRX0_P
### TCP0_TXRX1_N
### TCP0_TXRX1_P
### TCP0_VBUS
### TCP1_AUX_N
### TCP1_AUX_P
### TCP1_CC1
### TCP1_CC1_CN
### TCP1_CC2
### TCP1_CC2_CN
### TCP1_DN
### TCP1_DP
### TCP1_HPD
### TCP1_PPHV
### TCP1_PPHV_EN
### TCP1_SBU1
### TCP1_SBU1_CN
### TCP1_SBU2
### TCP1_SBU2_CN
### TCP1_TX0_N
### TCP1_TX0_P
### TCP1_TX1_N
### TCP1_TX1_P
### TCP1_TXRX0_N
### TCP1_TXRX0_P
### TCP1_TXRX1_N
### TCP1_TXRX1_P
### TCP1_VBUS
### TCP_ADCIN1
### TCP_ADCIN2
### TCP_DRAIN1
### TCP_DRAIN2
### TCP_LDO_1V8
### TCP_LDO_3V3
### TCP_PA_EXT_EN
### TCP_PB_EXT_EN
### TCP_PP_5V
### TCP_SPI_3V3
### TCP_SPI_CLK
### TCP_SPI_CS
### TCP_SPI_HOLD
### TCP_SPI_MISO
### TCP_SPI_MOSI
### TCP_SPI_WP
### TCP_VIN_3V3
### USB_5V
### USB_EXT0_EN
### USB_EXT0_FLT
### USB_EXT0_SSRX0_N
### USB_EXT0_SSRX0_P
### USB_EXT0_SSRX1_N
### USB_EXT0_SSRX1_P
### USB_EXT0_USB2_N
### USB_EXT0_USB2_P
### USB_EXT0_VBUS
### USB_EXT1_EN
### USB_EXT1_FLT
### USB_EXT1_SSRX0_N
### USB_EXT1_SSRX0_P
### USB_EXT1_SSRX1_N
### USB_EXT1_SSRX1_P
### USB_EXT1_USB2_N
### USB_EXT1_USB2_P
### USB_EXT1_VBUS
### VBAT
### VBUS
### VSYS
### VSYS_SOM
### VSYS_SW_EN

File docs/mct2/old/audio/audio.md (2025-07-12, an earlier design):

Originally as a multimedia-oriented device, MediaCow Touch 2 contains a complex audio subsystem.

## Audio DAC/ADC
An audio CODEC IC may be used if not separate DAC and ADC ICs. 

## PCB Design
The audio CODEC IC, amplifiers and headphone jack connectors are on a separate PCB.

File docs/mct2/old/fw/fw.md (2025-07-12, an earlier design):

## BIOS image
MediaCow Touch 2 is to use coreboot, customized for use on the device. 

### Removable BIOS Feature
MediaCow Touch 2 follows the principles of the document titled ["State Considered Harmful"](https://blog.invisiblethings.org/papers/2015/state_harmful.pdf).

Alongside the optional on-board SPI flash provided by an SOIC-8 socket, there is the option of having no SPI flash device on-board and instead, the BIOS image is loaded from the embedded controller (SMEC) that reads the image from either an externally accessible microSD or USB drive. The embedded controller (SMEC) does not have any internal flash memory and its firmware would be read from the same drive.

This is a feature found on very few devices and MediaCow Touch 2 may be the first tablet or handheld with it.

Other components such as the Ethernet controller IC that rely on an external SPI flash memory device for configuration may also have the embedded controller load this data instead. An exception to this may be the USB Type-C controller though its flash may be socketed anyway.

By default, the LattePanda Mu contains an 64GB eMMC for user-accessible storage and an SPI flash for BIOS. It may be possible to remove these devices from the module or be provided a LattePanda Mu that does not have these devices populated.

### Other microcontrollers
If other microcontrollers are present in the design for whatever reason. Microcontroller parts used may be ones that do not have have integrated flash memory or EEPROM. An example of this is the Raspberry Pi RP2040 and some RP2350 devices.

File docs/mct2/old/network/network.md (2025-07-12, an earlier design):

## Wi-Fi/BT and WWAN module slots
The carrier board has one M.2 Key B slot and one M.2 Key E slot for adding Wi-Fi/Bluetooth and cellular connectivity. This was common with older laptops though is unfortunately not seen in many modern devices where instead the wireless module is soldered onto the motherboard. Though it is understandable in some cases where size is important, such as the [Valve Steam Deck](https://www.ifixit.com/Guide/Steam+Deck+Chip+ID/147811).

Providing wireless connectivity through M.2 slots allows for wireless to be an optional feature, leading to both privacy and security benefits. Another benefit is that wireless modules can be easily replaced for repairability and security purposes.

## Ethernet
MediaCow Touch 2 provides a single gigabit Ethernet port for wired networking. Like wireless, wired networking is also provided by an M.2 module. While allowing the Ethernet NIC to be replaced or removed, this would simplify the carrier board design by not having to implement the Ethernet controller on the carrier board.

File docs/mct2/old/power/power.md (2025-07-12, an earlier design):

Power management is one of the more complex parts of the project. Power regulators are expected to dominate the amount of ICs (integrated circuits; chips) used in the design.

## Overview
As a tablet computer, MediaCow Touch 2 contains a rechargeable battery pack.

MediaCow Touch 2 would charge off from USB Type-C Power Delivery that is supported by both USB Type-C ports present.

## LattePanda Mu
The LattePanda supports a wide voltage input of 9v to 20v, this allows the module to be powered directly off from system power that could be anywhere between 12v (worst case) and 20v.

## Battery
With difficulties finding battery packs for DIY usage that have the ability to report state-of-charge; have a fuel gauge. I used a battery pack intended as a replacement battery pack for an existing laptop, specifically the HP FM08 used in the HP OMEN 17-an008ca among others. The pinout and connector type is unknown at the moment.

In January 2025, I had the idea of making my own battery pack, using four of Adafruit's 10050mAh 3.7v battery packs in a 4S3P configuration using a custom BMS board, resulting in a 14.8v 10Ah (148.74Wh) battery pack. This is about 3.72 times the battery capacity of the [Steam Deck](https://www.steamdeck.com/en/hardware) at 40Wh and 1.7 times the capacity of the HP FM08 battery pack at 86Wh.

## Voltage Supplies

### System Power - VSYS
System Power is the main supply that is directly from the battery or USB Type-C ports. Worst case voltage for the battery is 12v. Power from USB Type-C is expected to be 20v.

This supply is always available while the system is powered on or off.

### LattePanda Mu input voltage - VSYS_SW
VSYS_SW is a switched power supply that powers the LattePanda Mu. An Infineon BTS7003-1EPP is used to switch the voltage. Due to the relatively high voltage of VSYS, only automotive-grade parts such as the BTS7003-1EPP were available.

The BTS7003-1EPP has a unique sense pin feature that allows a microcontroller to read the voltage and current, a bit of research was done to see how this could be implemented with the SP7021, even going to a junkyard to see if I could find this component in a vehicle. Due to the part being recent, with the datasheet dating 2018, I have not been able to find this part in a vehicle. I used this as more of an excuse to go to the junkyard.

As recommended in the datasheet for the BTS7003-1Epp, a zener diode on the sense output is used to protect the microcontroller from possible overvoltage.

### SMEC input voltage - SMEC_5V
SMEC_5V is a pre-regulated 5v supply that feeds directly to the PMIC for the SP7021.

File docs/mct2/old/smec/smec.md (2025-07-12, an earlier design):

SMEC, System Management Embedded Controller, is a dedicated microprocessor that handles various system management tasks.

## Overview

### History

#### Previous Designs
An embedded controller was expected to be present in the design since the beginning of the project in 2021. The original MediaCow Touch from 2020 had something that could be considered an embedded controller: a Teensy LC board that made use of a NXP/Freescale Kinetis MKL26Z64VFT4 microcontroller though its only purpose was to control the button board on the side of the case.

Photos from 2021 development period show that the embedded controller was to be a Microchip PIC32MX MIPS microcontroller.

#### Current
The initial block diagram sent to LattePanda at the beginning of the current project in June 2024 showed that the design did not have an embedded controller. The team suggested that I should add one.

I started out with an STMicroelectronics STM32L-series microcontroller though this changed later on.

With the introduction of the side-mounted display, this changed. On September 11, 2024, I officially switched to the Sunplus/Tibbo SP7021 System in Package. 
There are several reasons why I went with a System in Package over a common, low-power, microcontroller. The use of a dedicated processor as the embedded controller would have the device unique to other tablet designs. SMEC ended up being a project on its own with its own embedded Linux distribution, assets and software.

Dedicated SoCs have been present on chiefly server hardware, called the "Baseband Management Controller" or BMC that provides a web interface to remotely manage the system. SMEC is similar in hardware though it is not intended for remote management since it is not networked by default (Ethernet interfaces may be exposed though unused). MediaCow Touch 2 may be the first tablet computer to contain a dedicated microprocessor that can act as a BMC.

## Features

### Power Management
SMEC controls various power regulators on board along with communicating with the USB Type-C PD and battery management ICs. 

### Display
SMEC controls the dedicated side-mounted display. See Display subpage below for more details.

### Audio
SMEC acts as a DSP for audio input and output.

SMEC can possibly playback audio on its own.

### Firmware Management
A unique feature of MediaCow Touch 2 is that SMEC is capable of emulating an SPI flash device where the system (LattePanda Mu) reads from it to load the BIOS image.

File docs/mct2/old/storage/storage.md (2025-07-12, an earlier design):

## Overview

## 2.5" SATA Drive Support
Support for 2.5" SATA was planned but sourcing PCIe-SATA host controllers was not possible for individuals, this being the same issue with finding video bridge ICs.

Mounting for an 2.5" drive may be available as it may be possible to use an off-the-shelf M.2 NVMe-SATA adapter to provide SATA.

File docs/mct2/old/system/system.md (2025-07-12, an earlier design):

MediaCow Touch 2 makes use of the LattePanda Mu System on Module.

## Hardware
Originally, MediaCow Touch 2 was to use the N100 variant of the LattePanda Mu until the N305 variant became available in January 2025.

Though the N100 and N305 are intended as a low-power mobile solution for devices such as Chromebooks, it is significantly more powerful than any ARM-based SoC I could find on a System on Module, including the Rockchip RK3399 on the Graperain GR3399 that was originally going to be used in the project and even more than the Allwinner A64 that was present in MediaCow Touch 1.

After testing the System on Module with a [couple games in early July 2024 on provided Windows 11](/blog/mct2_p1/), I determined that the N100's performance is more than enough for what I expected to use the device for. 

### Memory
On the product page, it is mentioned that the module has optional "in-band ECC". This means that a part of the memory would be reserved for storing error correction data. This is different from ECC memory where there are dedicated DRAM ICs and extra memory bus bits for storing error correcting codes. I do not consider this feature to be "true ECC" memory and it may be disabled if it has too much of an impact over performance.

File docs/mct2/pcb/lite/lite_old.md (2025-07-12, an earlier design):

To lower complexity and cost, a single PCB is used for MediaCow Touch 2 Lite "Curitiba".

## Net Descriptions
This section covers each net in the schematic for the MediaCow Touch 2 Lite "Curitiba" carrier board.

### AC_ - Audio CODEC
These connections relate to the audio CODEC. It surrounds the use of the 92HD95 CODEC. It is not named HDA_ in case an I2S CODEC is used. Names here are derived from the CODEC's pin names.

#### AC_PORTA_R/AC_PORTA_L
CODEC analog output to headphone jack.

#### AC_PORTB_R/AC_PORTB_L
CODEC analog input from microphone jack.

#### AC_PORTD_RP/AC_PORTD_RN/AC_PORTD_LP/AC_PORTD_LN
Analog output for internal speaker array, making use of integrated audio amplifiers.

| 92HD95 Pin | Net Name |
| --- | --- |
| PORTD+_R | AC_PORTD_RP |
| PORTD-_R | AC_PORTD_RN |
| PORTD+_L | AC_PORTD_LP |
| PORTD-_L | AC_PORTD_LN |

#### AC_DMIC_CLK
Clock signal from digital microphone

#### AC_DMIC_D0
Data from digital microphone 1

#### AC_DMIC_D1
Data from digital microphone 2

May be unused if the webcam module being used has one microphone only.

#### AC_PCBEEP
This net is for controlling the PC Beep feature of the CODEC. It is connected directly to the embedded controller (SMEC).

### BM_ - Battery Management
These connections relate to the BQ25723 battery management IC and the battery pack BMS.

### EC_ - Embedded Controller connections

#### EC_PM_I2C_ - Embedded Controller Power Management I2C bus
This I2C bus is used for communication between the embedded controller and the following:

- TPS65988 - Type-C PD controller
- MPS8859 Programmable buck-boost converter - TCP_PPHV0 source
- MPS8859 Programmable buck-boost converter - TCP_PPHV1 source
 
#### EC_BM_I2C_ - Embedded Controller Battery Management I2C bus
This I2C bus is used for communication between the embedded controller and the following:

- BQ25723 - Battery management IC
- ??? - Pack BMS/fuel gauge

#### EC_IOVDD
This supply is used as a reference voltage for IO. Any pull-up resistors for connections to the embedded controller are to be connected to this net.

This net is likely to be 3.3v.

### HDMI_ - HDMI Subsystem
The TPD12S016 is used as the HDMI protection IC.

#### HDMI_5V
This is the 5V supply that connects to the VCC5V of the HDMI protection IC.

#### HDMI_5V_CN
HDMI_5V_CN is the connection between the HDMI connector and the HDMI protection IC's 5V output.

#### HDMI_CLKN/HDMI_CLKP
Differential pair for HDMI clock.

#### HDMI_CT_HPD
HDMI_CT_HPD is used to control the detection scheme on the HDMI protection IC.

#### HDMI_D0N/HDMI_D0P
First differential pair for HDMI data.

#### HDMI_D1N/HDMI_D1P
Second differential pair for HDMI data.

#### HDMI_D2N/HDMI_D2P
Third differential pair for HDMI data.

#### HDMI_HPD
HDMI_HPD is used for hot-plug detection and is connected to the HDMI protection IC.

#### HDMI_LS_OE
HDMI_LS_OE is used to control the integrated level shifter on the HDMI protection IC.

#### HDMI_SCL/HDMI_SDA
HDMI_SCL/HDMI_SDA are used for I2C communication and are connected to the HDMI protection IC.

#### HDMI_CN_SCL/HDMI_CN_SDA
These are connections for I2C and are connected between the HDMI protection IC and the HDMI connector.

#### HDMI_UTILITY
This connection is unused but is connected to a test point for debugging.

#### HDMI_VCCA
This is the 3.3V supply for the HDMI protection IC.

### M2E - M.2 Key E connector
The M.2 Key E connector can be used for a variety of purposes. The intended purpose is for use with a M.2 Wi-Fi/BT module.

#### M2E_WDISABLE1
First WDISABLE pin for the M.2 Key E connector. Behavior depends on the module being used.

#### M2E_WDISABLE2
Second WDISABLE pin for the M.2 Key E connector. Behavior depends on the module being used.

### SOM_ - SoM connections
These connections are between the SoM (LattePanda Mu) and other components on the carrier board.

#### SOM_FANx_PWM/SOM_FANx_TAC/SOM_TSENSE
These pins may be unused as MediaCow Touch 2 Lite would use a fanless design while on MediaCow Touch 2 (Full), fans are to be controlled by SMEC.

#### SOM_GSX_DOUT/SOM_GSX_SLOAD/SOM_GSX_DIN/SOM_GSX_RESET/SOM_GSX_CLK
Exposed as GPIO on the LattePanda Mu, these pins have the alternate mode of providing the GPIO Serial Expander interface of the N100/N305. These pins may be unused since neither version of MediaCow Touch 2 would make use of GPIO expansion on the N100/N305. Instead, pins are exposed for debugging purposes.

| Symbol Pin Name | Label Name |
| --- | --- |
| GPP_F12 | SOM_GSX_DOUT  |
| GPP_F13 | SOM_GSX_SLOAD |
| GPP_F14 | SOM_GSX_DIN |
| GPP_F15 | SOM_GSX_RESET |
| GPP_F16 | SOM_GSX_CLK |

#### SOM_HDA_ - SoM HD Audio connections
These are the connections from the SoM to the HD Audio CODEC.

- SOM_HDA_BCLK - Bit Clock
- SOM_HDA_RST - Reset, active low
- SOM_HDA_SDIN - Data from CODEC to SoM
- SOM_HDA_SDOUT - Data from SoM to CODEC
- SOM_HDA_SYNC - Sync

#### SOM_HSIO_ - SoM HSIO connections
The HSIO connections on the Intel N100/N305 are mostly used for providing PCIe lanes with the only two being used for other purposes are HSIO0 and HSIO1.

| Port | Purpose | PCIe Device | PCIe Controller |
| --- | --- | --- | --- |
| HSIO 0  | Ext. USB 3  | N/A | Controller #1 |
| HSIO 1  | Ext. USB 3  | N/A | Controller #1 |
| HSIO 2  | Reserved | N/A | Controller #1 |
| HSIO 3  | Reserved | N/A | Controller #1 |
| HSIO 6  | M.2 Key E | 1 | Controller #2 |
| HSIO 8  | M.2 Key M | 2 | Controller #3 |
| HSIO 9  | M.2 Key M | 2 | Controller #3 |
| HSIO 10 | M.2 Key M | 2 | Controller #3 |
| HSIO 11 | M.2 Key M | 2 | Controller #3 |

- The first two HSIO lanes are used as USB 3.2 connected to the two USB Type-C ports. 
- The M.2 Key E slot is intended for use with a Wi-Fi/BT module, with USB 2.0 provided alongside a PCIe lane.
- The M.2 Key M slots are intended for use with a M.2 NVMe storage module. This slot could also be used for a M.2 SATA module.

##### SOM_HSIO0
SOM_HSIO0 is used for providing USB 3.x for the first USB 3 Type-A port.

| SoM Net Name | Device Net Name  |
| --- | --- |
| SOM_HSIO0_TX_P  | USB_EXT0_SSRX0_P |
| SOM_HSIO0_TX_N  | USB_EXT0_SSRX0_N |
| SOM_HSIO0_RX_P  | USB_EXT0_SSRX1_P |
| SOM_HSIO0_RX_N  | USB_EXT0_SSRX1_N |

##### SOM_HSIO1
SOM_HSIO1 is used for providing USB 3.x for the second USB 3 Type-A port.

| SoM Net Name | Device Net Name  |
| --- | --- |
| SOM_HSIO1_TX_P  | USB_EXT1_SSRX0_P |
| SOM_HSIO1_TX_N  | USB_EXT1_SSRX0_N |
| SOM_HSIO1_RX_P  | USB_EXT1_SSRX1_P |
| SOM_HSIO1_RX_N  | USB_EXT1_SSRX1_N |

##### SOM_HSIO2
SOM_HSIO2 is currently unused on MediaCow Touch 2 Lite "Curitiba".

##### SOM_HSIO3
SOM_HSIO3 is currently unused on MediaCow Touch 2 Lite "Curitiba".

##### SOM_HSIO6
SOM_HSIO6 is used for providing a single PCIe lane for the M.2 Key E slot.

| SoM Net Name | Device Net Name  |
| --- | --- |
| SOM_HSIO6_TX_P  | PCIE_M2E_TX_P |
| SOM_HSIO6_TX_N  | PCIE_M2E_TX_N |
| SOM_HSIO6_RX_P  | PCIE_M2E_RX_P |
| SOM_HSIO6_RX_N  | PCIE_M2E_RX_N |

##### SOM_HSIO8/SOM_HSIO9/SOM_HSIO10/SOM_HSIO11
SOM_HSIO8/SOM_HSIO9/SOM_HSIO10/SOM_HSIO11 are used for providing four PCIe lanes for the M.2 Key M slot.

| SoM Net Name | Device Net Name  |
| --- | --- |
| SOM_HSIO8_TX_P  | PCIE_M2M_TX0_P |
| SOM_HSIO8_TX_N  | PCIE_M2M_TX0_N |
| SOM_HSIO8_RX_P  | PCIE_M2M_RX0_P |
| SOM_HSIO8_RX_N  | PCIE_M2M_RX0_N |
| SOM_HSIO9_TX_P  | PCIE_M2M_TX1_P |
| SOM_HSIO9_TX_N  | PCIE_M2M_TX1_N |
| SOM_HSIO9_RX_P  | PCIE_M2M_RX1_P |
| SOM_HSIO9_RX_N  | PCIE_M2M_RX1_N |
| SOM_HSIO10_TX_P | PCIE_M2M_TX2_P |
| SOM_HSIO10_TX_N | PCIE_M2M_TX2_N |
| SOM_HSIO10_RX_P | PCIE_M2M_RX2_P |
| SOM_HSIO10_RX_N | PCIE_M2M_RX2_N |
| SOM_HSIO11_TX_P | PCIE_M2M_TX3_P |
| SOM_HSIO11_TX_N | PCIE_M2M_TX3_N |
| SOM_HSIO11_RX_P | PCIE_M2M_RX3_P |
| SOM_HSIO11_RX_N | PCIE_M2M_RX3_N |

#### SOM_I2C
Usage of I2C on the SoM is minimal in both versions of MediaCow Touch 2 as the embedded controller is used for most I2C communication.

I2C2_SDA/I2C2_SCL is the only I2C bus used on the SoM.

##### SOM_I2C2_SCL/SOM_I2C2_SDA
SOM_I2C2_SCL/SOM_I2C2_SDA are used for communication between the SoM and the embedded controller.

#### SOM_I2S_
SOM_I2S_ connections are unused when the Tempo/IDT 92HD95 CODEC is used.

These connections are labeled in case another audio CODEC is used.

#### SOM_RTC_VBAT
SOM_RTC_VBAT is used to power the RTC independently of the main power supply. A coin cell battery on-board supplies this power.

#### SOM_SATAXPCIE0/SOM_SATAXPCIE1
SOM_SATAXPCIE0 is also known as GPP_E0 and SOM_SATAXPCIE1 is also known as GPP_A12.

SOM_SATAXPCIE0/SOM_SATAXPCIE1 is unused since neither version of MediaCow Touch 2 makes use of integrated SATA and is instead, the pins are exposed for debugging purposes.

#### SOM_SBK0/SOM_SBK1/SOM_SBK2/SOM_SBK3
SOM_SBK0/SOM_SBK1/SOM_SBK2/SOM_SBK3, being GPP_D0, GPP_D1, GPP_D2, and GPP_D3 respectively are used as part of the N100/N305's Serial Blink functionality. They are used for debugging purposes. They are exposed through test points or a pin header if there is enough space left on the PCB.

Each pin has this description in the Intel Processor and Intel Core i3 N-Series Datasheet Volume 1:
```
This function provides the capability to serialize POST or
other messages on the pin to a serial monitor. The Serial Blink message is
programmed through the Serial Blink Command/Status and Serial Blink Data
registers. Refer to Volume 2 for details.
```

#### SOM_SML_SCL/SOM_SML_SDA/SOM_SML_ALT
SOM_SML is used to communicate with the N100/N305's integrated USB Type-C ports using a protocol called SMLink. Not much is known about this protocol but it is crucial for the function of the USB Type-C ports and battery management.

#### SOM_UARTx
SOM_UART0_TX/RX is used as a serial console for debugging. It is exposed using a header on the carrier board and may not be connected to anything else.

#### SOM_USBx
This table describes the purpose of each USB port on the SoM.

| Port | Purpose |
| --- | --- |
| SOM_USB2_P1 | Ext. USB 3  |
| SOM_USB2_P2 | Ext. USB 3  |
| SOM_USB2_P3 | M.2 Key E |
| SOM_USB2_P4 | |
| SOM_USB2_P5 | TCP Port 1  |
| SOM_USB2_P6 | TCP Port 2  |
| SOM_USB2_P7 | Webcam |
| SOM_USB2_P8 | |

Each USB pair has the following nets:
- SOM_USB2_Px_P
- SOM_USB2_Px_N

#### SOM_VSYS
This is the main power supply for the SoM, after the BTS7006-1EPP load switch that is controlled by the embedded controller.

### TCP_ - USB Type-C Subsystem
A TPS65988 is used for USB Type-C management for both ports.

#### Type-C Port 0 - TCP0_

##### TCP0_DP/TCP0_DN
Differential pair for USB 2.0 over USB Type-C.

##### TCP0_HPD
USB Type-C Hot-Plug Detect used for DisplayPort alternate mode.

##### TCP0_TX0_P/TCP0_TX0_N
First differential pair for USB 3.0 over USB Type-C.

220nF capacitors are in-line between this net and the connector as recommended.

A TPD4USB_EXT30 is used for overvoltage protection on these lines.

##### TCP0_TX1_P/TCP0_TX1_N
Second differential pair for USB 3.0 over USB Type-C.

220nF capacitors are in-line between this net and the connector as recommended. 

A TPD4USB_EXT30 is used for overvoltage protection on these lines.

##### TCP0_TXRX0_P/TCP0_TXRX0_N
Differential pair for USB 3.0 over USB Type-C.

##### TCP0_TX0_P/TCP0_TX0_N
Differential pair for USB 3.0 over USB Type-C.

#### Type-C Port 1 - TCP1_

##### TCP1_DP/TCP1_DN
Differential pair for USB 2.0 over USB Type-C.

##### TCP1_HPD
USB Type-C Hot-Plug Detect used for DisplayPort alternate mode.

##### TCP1_TX0_P/TCP1_TX0_N
First differential pair for USB 3.0 over USB Type-C.

220nF capacitors are in-line between this net and the connector as recommended.

A TPD4USB_EXT30 is used for overvoltage protection on these lines.

##### TCP1_TX1_P/TCP1_TX1_N
Second differential pair for USB 3.0 over USB Type-C.

220nF capacitors are in-line between this net and the connector as recommended. 

A TPD4USB_EXT30 is used for overvoltage protection on these lines.

##### TCP1_TXRX0_P/TCP1_TXRX0_N
Differential pair for USB 3.0 over USB Type-C.

##### TCP1_TX0_P/TCP1_TX0_N
Differential pair for USB 3.0 over USB Type-C.

#### *Optional* - SPI Flash - TCP_SPI_
As a precaution, pads for an SPI flash memory are included on the carrier board in case it cannot be configured by an external device such as SMEC.

##### TCP_SPI_3V3
This is the 3.3V supply for the SPI flash, it is provided by the integrated LDO in the TPS65988 as the description for the pin suggests that it is what is used to power the SPI flash.

##### TCP_SPI_CS
This is the chip select pin for the SPI flash.

##### TCP_SPI_CLK
This is the clock pin for the SPI flash.

##### TCP_SPI_MOSI
This is the master (TPS65988) output, slave (SPI flash) input pin for the SPI flash.

The pull-up resistor is marked as Do not Populate and exists as a precautionary measure for the case where a pull-up resistor may be needed.

##### TCP_SPI_MISO
This is the master (TPS65988) input, slave (SPI flash) output pin for the SPI flash.

##### TCP_SPI_WP
This net is unused and only exists to name the connection between the pin and a pull-up resistor.

##### TCP_SPI_HOLD
This net is unused and only exists to name the connection between the pin and a pull-up resistor.

### VSYS_ - System Power
VSYS itself is a net that is after the battery charge IC, it can be anywhere within 12 to 20v.

#### VSYS_SOM
This is the switched power supply for the SoM, after the BTS7006-1EPP load switch that is controlled by the embedded controller.

#### VSYS_SW_EN
This is the enable pin for the load switch for the SoM.

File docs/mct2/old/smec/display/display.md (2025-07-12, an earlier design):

While seemingly unneccesary, SMEC has a dedicated display mounted on the side of the device. This display is used to interact with the embedded controller directly, independent of the system.

## User Interface
Along with the keypad, the side-mounted display includes a capacitive touchscreen. 

## RGB-MIPI
An RGB-MIPI video bridge is required as the SP7021 does not have a MIPI DSI output. RGB-MIPI bridge ICs are scarce. I have considered Toshiba TC358778XBG though I was unable to receive extended information from Toshiba for this part. Another option is the use of an FPGA such as the Lattice LIF-MD6000-6MG81I where there is IP available for converting a variety of video standards to MIPI DSI/CSI, the IP is however non-free and may cost too much for a small-scale project such as this.

Possible solutions for RGB-MIPI

In February 2025, I decided to make use of an **FPGA** for the RGB-MIPI bridge, though more expensive, it offers the most flexibility.

### RGB-MIPI Bridge Placement
In order to be able to use a larger variety of displays without making changes to the carrier PCB, the RGB-MIPI bridge IC would be placed on the button PCB (or a separate PCB if it is worth increasing the PCB count).

## Options
Multiple displays have been considered for use as the side-mounted display. The Tailorpixels TTH318BVE-01C was chosen due to its short height, being less than an inch (25.4mm), which reduces the overall thickness of the device. It is also unique in that it is an AMOLED display. It appears to have been introduced in November 2024 with its datasheet being dated August 13, 2024, which is likely why I have not seen it before.

### WF0299ATYAC2MNR0

- Vendor: Winstar Display
- Technology: IPS LCD
- Video Interface: MIPI DSI
- Resolution: 800x268
- Touch Interface: I2C
- Module Dimensions: 26.52mm x 78.2mm x 2.46mm
- Active Area: 24.12mm x 72.0mm

### MDT0299AIH-RGB

- Vendor: Midas Displays
- Technology: IPS LCD
- Video Interface: MIPI DSI
- Resolution: 800x268
- Touch Interface: SPI
- Module Dimensions: 26.96mm x 80.08mm x 1.66mm
- Active Area: 24.12mm x 72.00mm

### TOH323XVT-01C

- Vendor: Tailorpixels
- Technology: AMOLED
- Video Interface: MIPI DSI
- Resolution: 928x262
- Touch Interface: SPI
- Module Dimensions: 23.80mm x 81.05mm x 0.63mm
- Active Area: 22.008mm x 77.952mm

### TTH318BVE-01C

- Vendor: Tailorpixels
- Technology: IPS LCD
- Video Interface: MIPI DSI
- Resolution: 960x288
- Touch Interface: I2C
- Module Dimensions: 25.5mm x 85.3mm x 4.19mm
- Active Area: 23.07mm x 76.9mm

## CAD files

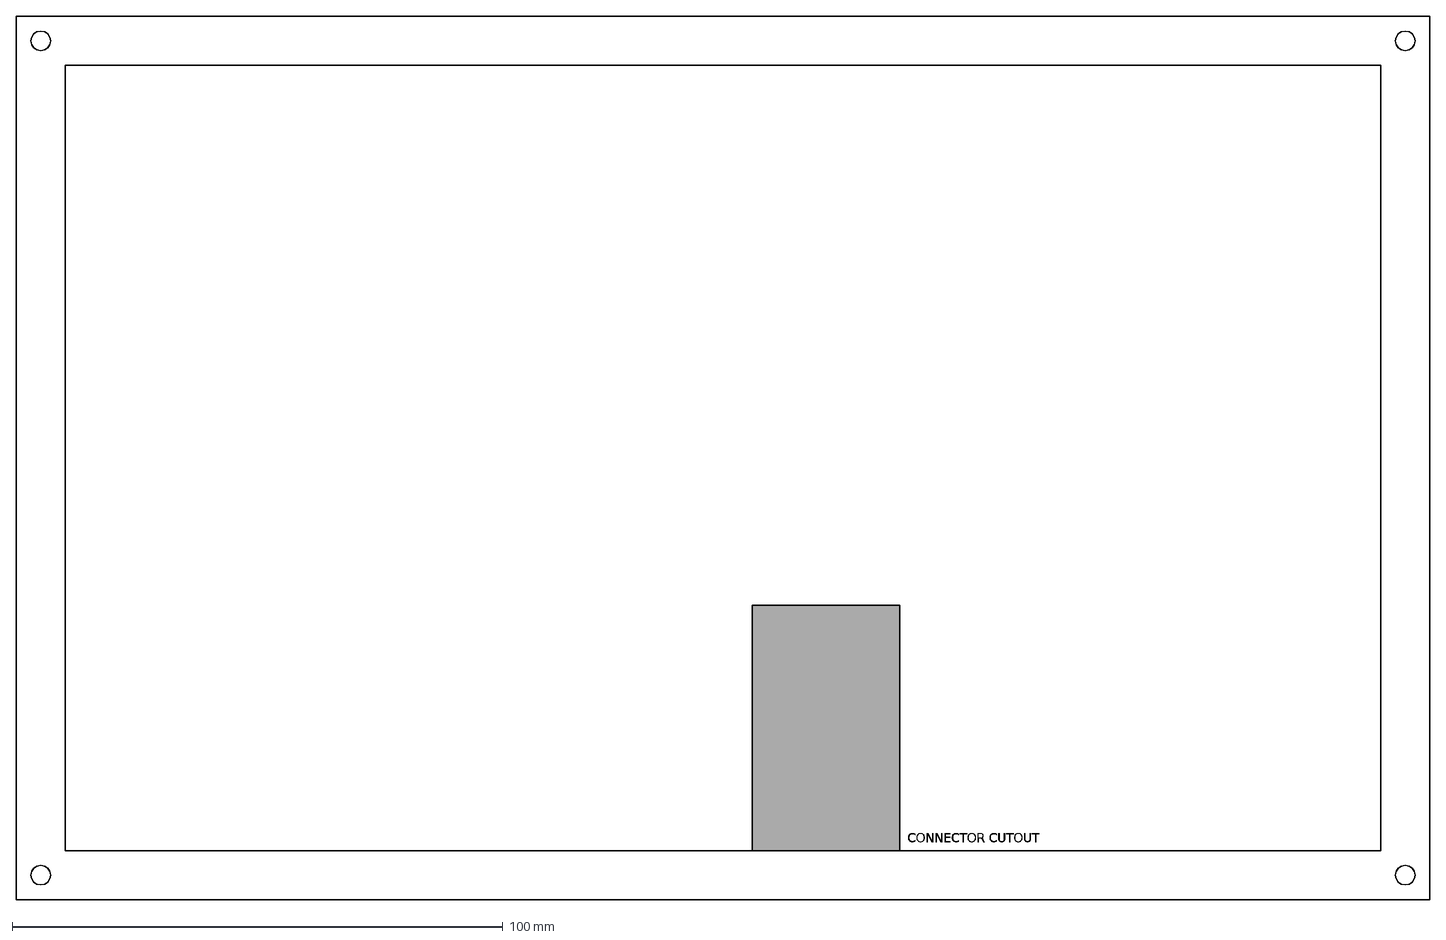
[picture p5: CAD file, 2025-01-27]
case/display_mount.dxf
CONNECTOR CUTOUT

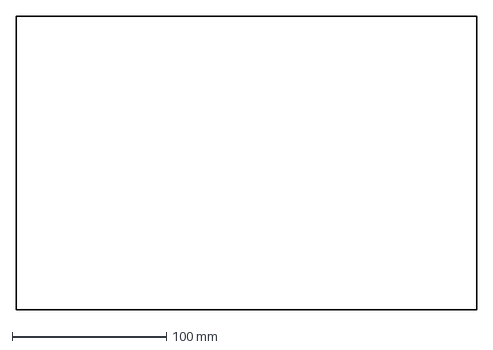
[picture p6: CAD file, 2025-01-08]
case/display_cover.dxf
298.0 x 190.0 mm

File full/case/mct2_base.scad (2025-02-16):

// MediaCow Touch 2 - CTCL 2021-2025
// Purpose: Base component
// Created: February 12, 2025
// Modified: February 16, 2025

// Module since this is getting out of hand
module _base_post(pos,nut=false) {
    translate(pos) {
        difference() {
            cube([case_post_size, case_post_size, case_internal_height]);
            if (nut) {
                translate([case_post_size / 2, case_post_size / 2, case_internal_height - nut_height]) {
                    cylinder(d=nut_od, h=nut_height + 5, $fn=6);
                }
            }
        }
    }
}

module base() {
    union() {
        difference() {
            cube(base_dims);

            // Cutout for the LCD mount
            translate([case_outer_wall_width, case_outer_wall_width, base_height - dispmount_height]) {
                // Add 1 to remove z-fighting in preview
                cube(dispmount_dims + [0,0,1]);
            }

            // Internal cutout
            translate([case_outer_wall_width + case_inner_wall_width, case_outer_wall_width + case_inner_wall_width, case_base_height]) {
                cube([base_width - (case_outer_wall_width * 2) - (case_inner_wall_width * 2), base_length - (case_outer_wall_width * 2) - (case_inner_wall_width * 2), base_height - case_base_height]);
            }
            // Mounting post cutouts
            // Bottom Left
            _base_post([case_outer_wall_width, case_outer_wall_width, case_base_height]);
            // Bottom Right
            _base_post([base_width - case_post_size - case_outer_wall_width, case_outer_wall_width, case_base_height]);
            // Top Left
            _base_post([case_outer_wall_width, base_length - case_post_size - case_outer_wall_width, case_base_height]);
            // Top Right
            _base_post([base_width - case_post_size - case_outer_wall_width, base_length - case_post_size - case_outer_wall_width, case_base_height]);
        }
        _base_post([case_outer_wall_width, case_outer_wall_width, case_base_height], true);
        // Bottom Right
        _base_post([base_width - case_post_size - case_outer_wall_width, case_outer_wall_width, case_base_height], true);
        // Top Left
        _base_post([case_outer_wall_width, base_length - case_post_size - case_outer_wall_width, case_base_height], true);
        // Top Right
        _base_post([base_width - case_post_size - case_outer_wall_width, base_length - case_post_size - case_outer_wall_width, case_base_height], true);
    }
}

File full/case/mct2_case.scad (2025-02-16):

// MediaCow Touch 2 - CTCL 2021-2025
// Purpose: Case design
// Created: July 7, 2024
// Modified: February 16, 2025

// Units: mm

// == Display dimensions ==
// Format: [length, height, thickness, aa distance right, aa distance left, aa distance top, aa distance bottom, connector distance from right, connector cutout width, connector cutout height]
// Option 1: DFRobot FIT0955
// +2mm for double-sided tape
lcd_dims_dfr = [268, 160, 5 + 2, 4.5, 5, 4, 10, 114, 25, 50];
// Option 2: Innolux N140HCR-GL2
// +2mm for double-sided tape
lcd_dims_inx_n140hcr = [313, 195, 3 + 2, 2.5, 2.5, 2.5, 20, 110, 25, 50];
// Option 3: Innolux N140JCN-EEL/-GS9
// NOTE: Dimensions from N140JCN-GS9 datasheet, 10mm added to cutout width
lcd_dims_inx_n140jcn = [307, 199, 5, 2.5, 2.5, 2.5, 7.6, 307 / 2, 230, 70];
// Selection
lcd_dims = lcd_dims_inx_n140jcn;

lcd_mount_base_height = 2;

dispcover_height = 2;

// == Case dimensions ==
// Thickness of the back of the case
case_base_height = 2;
// Distance from the bottom of the case to the bottom of the LCD mount
case_internal_height = 30;
// Width of the walls that the display mount rests on
case_inner_wall_width = 5;
// Width of the outer structural wall of the case
case_outer_wall_width = 5;
// Width of the posts the LCD mount bolts to
// WARNING: This also determines the LCD mount wall width
case_post_size = 10;

// == Mounting bolt dimensions ==
bolt_od = 4;
// Dimensions based off McMaster-Carr 90725A025
nut_od = 7;
nut_height = 4;

// == Calculated Values ==
// Base + LCD thickness
dispmount_height = lcd_mount_base_height + lcd_dims[2];
dispmount_width = lcd_dims[0] + (case_post_size * 2);
dispmount_length = lcd_dims[1] + (case_post_size * 2);
dispmount_dims = [dispmount_width, dispmount_length, dispmount_height];

base_height = case_base_height + case_internal_height + dispmount_height;
base_width = lcd_dims[0] + (case_post_size * 2) + (case_outer_wall_width * 2);
base_length = lcd_dims[1] + (case_post_size * 2) + (case_outer_wall_width * 2);
base_dims = [base_width, base_length, base_height];

include <mct2_base.scad>;
include <mct2_smec_smd.scad>;
include <mct2_dispmount.scad>;
include <mct2_dispcover.scad>;

view = "exploded"; // [assembled, exploded, base, dispmount, dispcover]

if (view == "assembled") {
    base();
    translate([case_outer_wall_width,case_outer_wall_width,case_internal_height + case_base_height]) dispmount();
    translate([0,0,base_height]) dispcover();
} else if (view == "exploded") {
    base();
    translate([case_outer_wall_width,case_outer_wall_width,50 + base_height]) dispmount();
    translate([0,0,100 + base_height + dispmount_height]) dispcover();
} else if (view == "base") {
    base();
} else if (view == "dispmount") {
    dispmount();
} else if (view == "dispcover") {
    dispcover();
}

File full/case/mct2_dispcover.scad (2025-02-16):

// MediaCow Touch 2 - CTCL 2021-2025
// Purpose: Display cover component
// Created: February 12, 2025
// Modified: February 16, 2025

module dispcover() {
    difference() {
        cube([base_width, base_length, dispcover_height]);
        translate([case_post_size + case_outer_wall_width, case_post_size + case_outer_wall_width + lcd_dims[6],-1]) {
            // Active area distances subtracted from the LCD dimensions so the cover covers the edges
            cube([lcd_dims[0] - lcd_dims[3] - lcd_dims[4], lcd_dims[1] - lcd_dims[5] - lcd_dims[6], dispcover_height + 2]);
        }
        translate([case_outer_wall_width, case_outer_wall_width, 0]) {
            // Mounting holes
            // Bottom Left
            translate([(case_post_size / 2), (case_post_size / 2), -1]) {
                cylinder(r=bolt_od / 2, h = dispmount_height + 2, $fn=360);
            }
            // Bottom Right
            translate([(dispmount_width - case_post_size / 2), (case_post_size / 2), -1]) {
                cylinder(r=bolt_od / 2, h = dispmount_height + 2, $fn=360);
            }
            // Top Left
            translate([(case_post_size / 2), (dispmount_length - case_post_size / 2), -1]) {
                cylinder(r=bolt_od / 2, h = dispmount_height + 2, $fn=360);
            }
            // Top Right
            translate([(dispmount_width - case_post_size / 2), (dispmount_length - case_post_size / 2), -1]) {
                cylinder(r=bolt_od / 2, h = dispmount_height + 2, $fn=360);
            }
        }
    }
}

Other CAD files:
full/case/smec_smd.dxf
case/base.dxf
full/old/case/base.dxf
full/case/mct2_dispmount.scad
full/case/mct2_smec_smd.scad
full/old/case/mct2_case_old.scad
lite/case/mct2_case.scad
lite/case/mct2_dispmount.scad
old/case/mct2_case.scad

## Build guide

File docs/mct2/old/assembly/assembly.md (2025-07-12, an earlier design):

## PCBA
MediaCow Touch 2 is expected to use a vast amount of components with numbers in the hundreds, possibly over a thousand. This may have hand-assembly impractical.

This poses a major challenge with being able to assemble these devices. PCBA services at quantities expected, being one to five, may be prohibitively expensive. The best course of action is to find a local place that has a pick-and-place (PNP) machine.

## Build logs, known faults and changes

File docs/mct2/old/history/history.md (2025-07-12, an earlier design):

## Beginning - 2021
The project technically started in early March 2021.

Ideas for MediaCow Touch 2 date back to March 2021 as mentioned before. The initial idea at the time surrounded the use of a soldered-down Rockchip RK3588 SoC with ten DDR4 DRAM ICs, specifically Nanya NT5AD1024M8A3, for 8GB of memory with ECC. This would have been almost impossible if not impossible for me to design at the time.

Halfway through March 2021 (March 12, 2021 according to emails), I decided to use the Graperain GR3399 System on Module that uses the Rockchip RK3399 and 2GB of DDR3 RAM (4x Samsung K4B4G1649E-BCMA). The development kit including the SoM was ordered in February 2022 but ended up never being used for the project. I preferred to use the MXM3.0 ("Gold Finger") format of the System on Module over the "Stamp hole" G3399 so during the assembly stage, I could just remove a couple screws to remove the module from the development kit and install the module into the prototype without having to desolder and risk damaging the module and/or development board.

## 2022 
In 2022, not knowing anything about circuit design and during the peak of the global chip shortage, I made multiple attempts to work on the project but I never got anywhere.

Later in 2022, I found out about various System on Modules that became available from Banana Pi, who supplied the board for MediaCow Touch 1, that used the newer and more powerful Rockchip RK3588.

## 2023
Throughout 2022 and 2023, I stopped working on hardware design projects due to their complexity and focused on software instead.

## 2024
In May 2024, I have found out about the [LattePanda Mu](https://www.lattepanda.com/lattepanda-mu) System on Module. This module uses an x86-64 processor instead of an ARM64 SoC. [According to Intel](https://ark.intel.com/content/www/us/en/ark/products/231803/intel-processor-n100-6m-cache-up-to-3-40-ghz.html), the N100 is targeted towards use in mobile devices. Using an x86 processor has its benefits including better software support and laptop-like performance. I signed up for the LattePanda Mu Free Trial Event to receive a LattePanda Mu System on Module along with its Lite Carrier Board.

In June 2024, I received the LattePanda Mu System on Module and Lite Carrier Board. I have since started working on the hardware design for the MediaCow Touch 2.

Throughout the development process from July 2024 to September 2024, the project became more and more complex. In November 2024, I decided to basically start over with the project, using what I had before as a reference.

## Late 2024 and early 2025
By January 2025, project development has slow, if not stopped, due to the lack of funding and me returning to college.

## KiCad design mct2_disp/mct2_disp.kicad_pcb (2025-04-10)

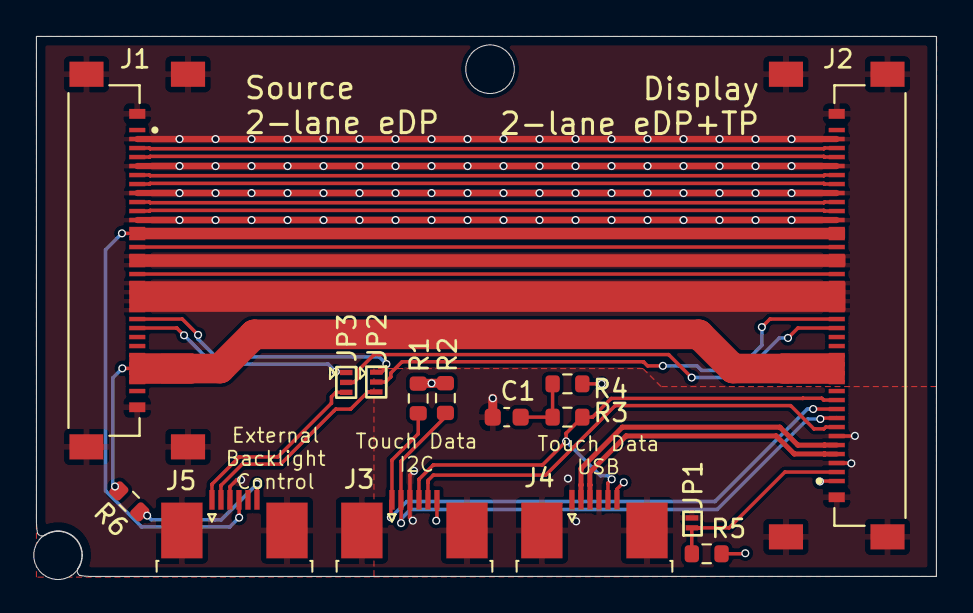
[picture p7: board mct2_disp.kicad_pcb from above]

Board: 4 copper layers, 50.0 x 30.0 mm, 17 parts (0 on the bottom side), 27 nets.

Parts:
C1: 4.7uF; C_0603_1608Metric
H1, H2: MountingHole; MountingHole_2.7mm_M2.5
J1: 20455-030E-76; IPEX_20455-030E-76
J2: 20455-040E-76; IPEX_20455-040E-76
J3: Touch Data - I2C; TE_0-1734839-6_1x06-1MP_P0.5mm_Horizontal
J4: Touch Data - USB; TE_0-1734839-6_1x06-1MP_P0.5mm_Horizontal
J5: External Backlight Control; TE_0-1734839-6_1x06-1MP_P0.5mm_Horizontal
JP1: Jumper_2_Open; SolderJumper-2_P1.3mm_Open_Pad1.0x1.5mm
JP2, JP3: Jumper_3_Open; SolderJumper-3_P1.3mm_Open_Pad0.3x0.7mm
R1, R2: 2.2K; R_0603_1608Metric
R3: 1K; R_0603_1608Metric
R4, R5: 10K; R_0603_1608Metric
R6: 0R; R_0603_1608Metric

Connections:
BL_EN: J2.19, JP2.2 (C)
BL_EN_EXT: J5.2, JP2.3 (B)
BL_EN_MU: J1.22, JP2.1 (A)
BL_PWM: J2.18, JP3.2 (C)
BL_PWM_EXT: J5.1, JP3.3 (B)
BL_PWM_MU: J1.23, JP3.1 (A)
BL_PWR: J1.26, J1.27, J1.28, J1.29, J2.12, J2.13, J2.14, J2.15, R6.2
EDP_AUX_N: J1.10, J2.31
EDP_AUX_P: J1.9, J2.32
EDP_HPD: J1.17, J2.24
EDP_TX0_N: J1.6, J2.35
EDP_TX0_P: J1.7, J2.34
EDP_TX1_N: J1.3, J2.38
EDP_TX1_P: J1.4, J2.37
GND: C1.2, J1.2, J1.5, J1.8, J1.11, J1.15, J1.16, J1.18, J1.19, J1.20, J1.21, J1.S1 (SHIELD), J1.S2 (SHIELD), J1.S3 (SHIELD), J1.S4 (SHIELD), J2.3, J2.6, J2.20, J2.21, J2.22, J2.23, J2.25, J2.26, J2.30, J2.33, J2.36, J2.39, J2.S1 (SHIELD), J2.S2 (SHIELD), J2.S3 (SHIELD), J2.S4 (SHIELD), J3.3, J3.MP (MountPin), J4.1, J4.4, J4.MP (MountPin), J5.3, J5.MP (MountPin), JP1.2 (B)
LCD_BIST: J1.14, J2.27
LCD_VCC: J1.12, J1.13, J2.28, J2.29, J5.4
unnamed: C1.1, R3.2, R4.2
unnamed: J5.6, R6.1
TP_I2C_SCL: J2.9, J3.1, R1.2
TP_I2C_SDA: J2.8, J3.2, R2.2
TP_INT: J2.7, J3.5
TP_RS: J2.2, JP1.1 (A), R5.2
TP_RST: J2.10, J3.4, J4.5, R3.1
TP_USB_N: J2.4, J4.3
TP_USB_P: J2.5, J4.2
TP_VCC: J2.1, J3.6, J4.6, R1.1, R2.1, R4.1, R5.1

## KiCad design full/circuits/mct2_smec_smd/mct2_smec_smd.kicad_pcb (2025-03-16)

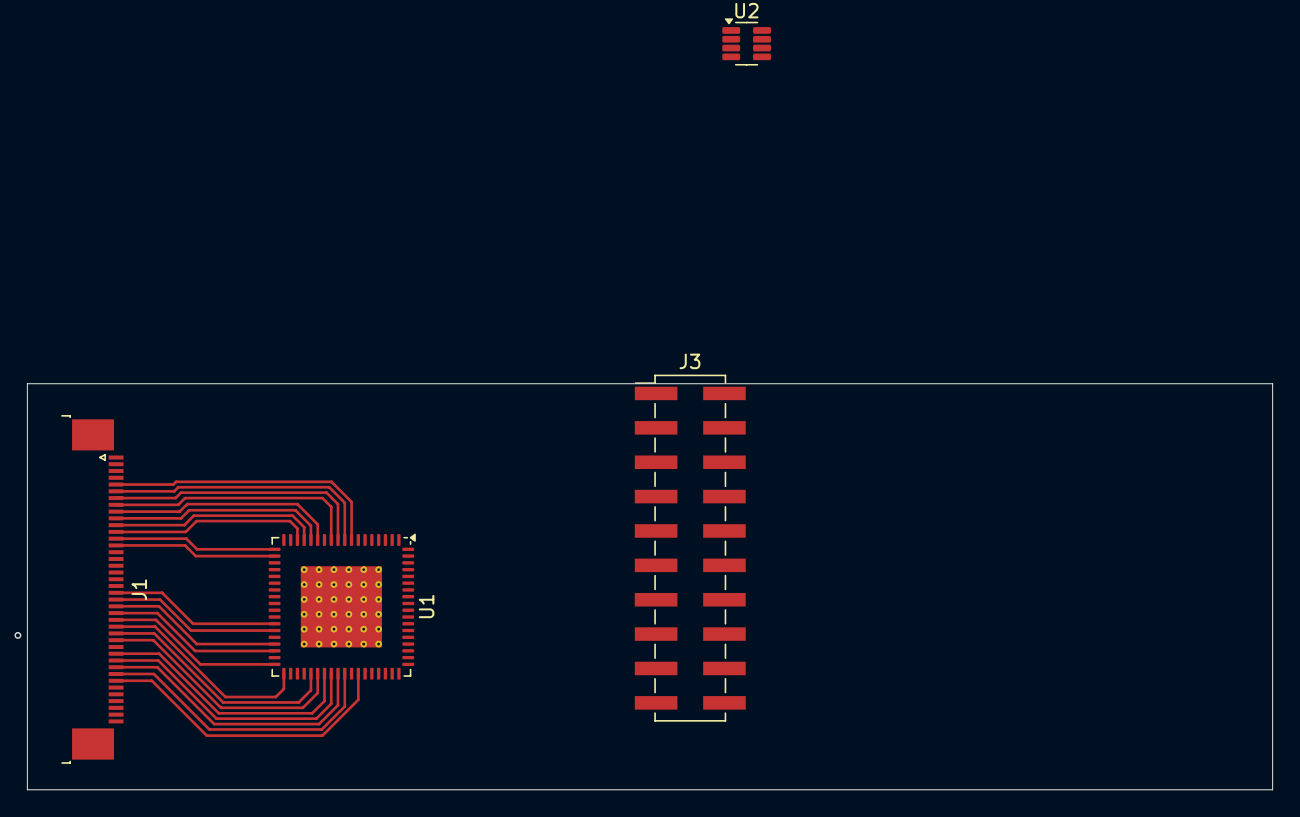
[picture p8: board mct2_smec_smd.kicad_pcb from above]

Board: 4 copper layers, 92.0 x 30.0 mm, 4 parts (0 on the bottom side), 28 nets.

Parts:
J1: Input 1x40 FPC; TE_4-1734839-0_1x40-1MP_P0.5mm_Horizontal
J3: Conn_02x15_Odd_Even; PinHeader_2x10_P2.54mm_Vertical_SMD
U1: LIFCL-17-7SG72C; QFN-72-1EP_10x10mm_P0.5mm_EP6x6mm_ThermalVias
U2: SOT-23-8

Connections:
GND: J1.3, J1.29, J1.36, J3.1, J3.2, J3.6, J3.7, J3.10, J3.13, J3.16, J3.19, J3.20
MIPI_CLK_N: J3.3, U1.3 (DPHY0_DN0)
MIPI_CLK_P: J3.5, U1.4 (DPHY0_DP0)
MIPI_D0_N: J3.15, U1.69 (DPHY0_CKN)
MIPI_D0_P: J3.17, U1.68 (DPHY0_CKP)
RGB_B0: J1.21, U1.30 (PB66A)
RGB_B1: J1.22, U1.31 (PB66B)
RGB_B2: J1.23, U1.33 (PB68A)
RGB_B3: J1.24, U1.34 (PB68B)
RGB_B4: J1.25, U1.36 (PB70A)
RGB_B5: J1.26, U1.37 (PB70B)
RGB_B6: J1.27, U1.41 (PR9A)
RGB_B7: J1.28, U1.42 (PR7A)
RGB_DE: J1.34, U1.48 (PR3B)
RGB_EN: J1.31, U1.44 (PR7B)
RGB_G0: J1.13, U1.19 (PB26A)
RGB_G1: J1.14, U1.20 (PB26B)
RGB_HSYNC: J1.32, U1.45 (PR5B)
RGB_PCLK: J1.30, U1.43 (PR9B)
RGB_R0: J1.5, U1.8 (PB30B)
RGB_R1: J1.6, U1.9 (PB30A)
RGB_R2: J1.7, U1.10 (PB20B)
RGB_R3: J1.8, U1.11 (PB20A)
RGB_R4: J1.9, U1.13 (PB16B)
RGB_R5: J1.10, U1.14 (PB16A)
RGB_R6: J1.11, U1.15 (PB18B)
RGB_R7: J1.12, U1.16 (PB18A)
RGB_VSYNC: J1.33, U1.46 (PR5A)

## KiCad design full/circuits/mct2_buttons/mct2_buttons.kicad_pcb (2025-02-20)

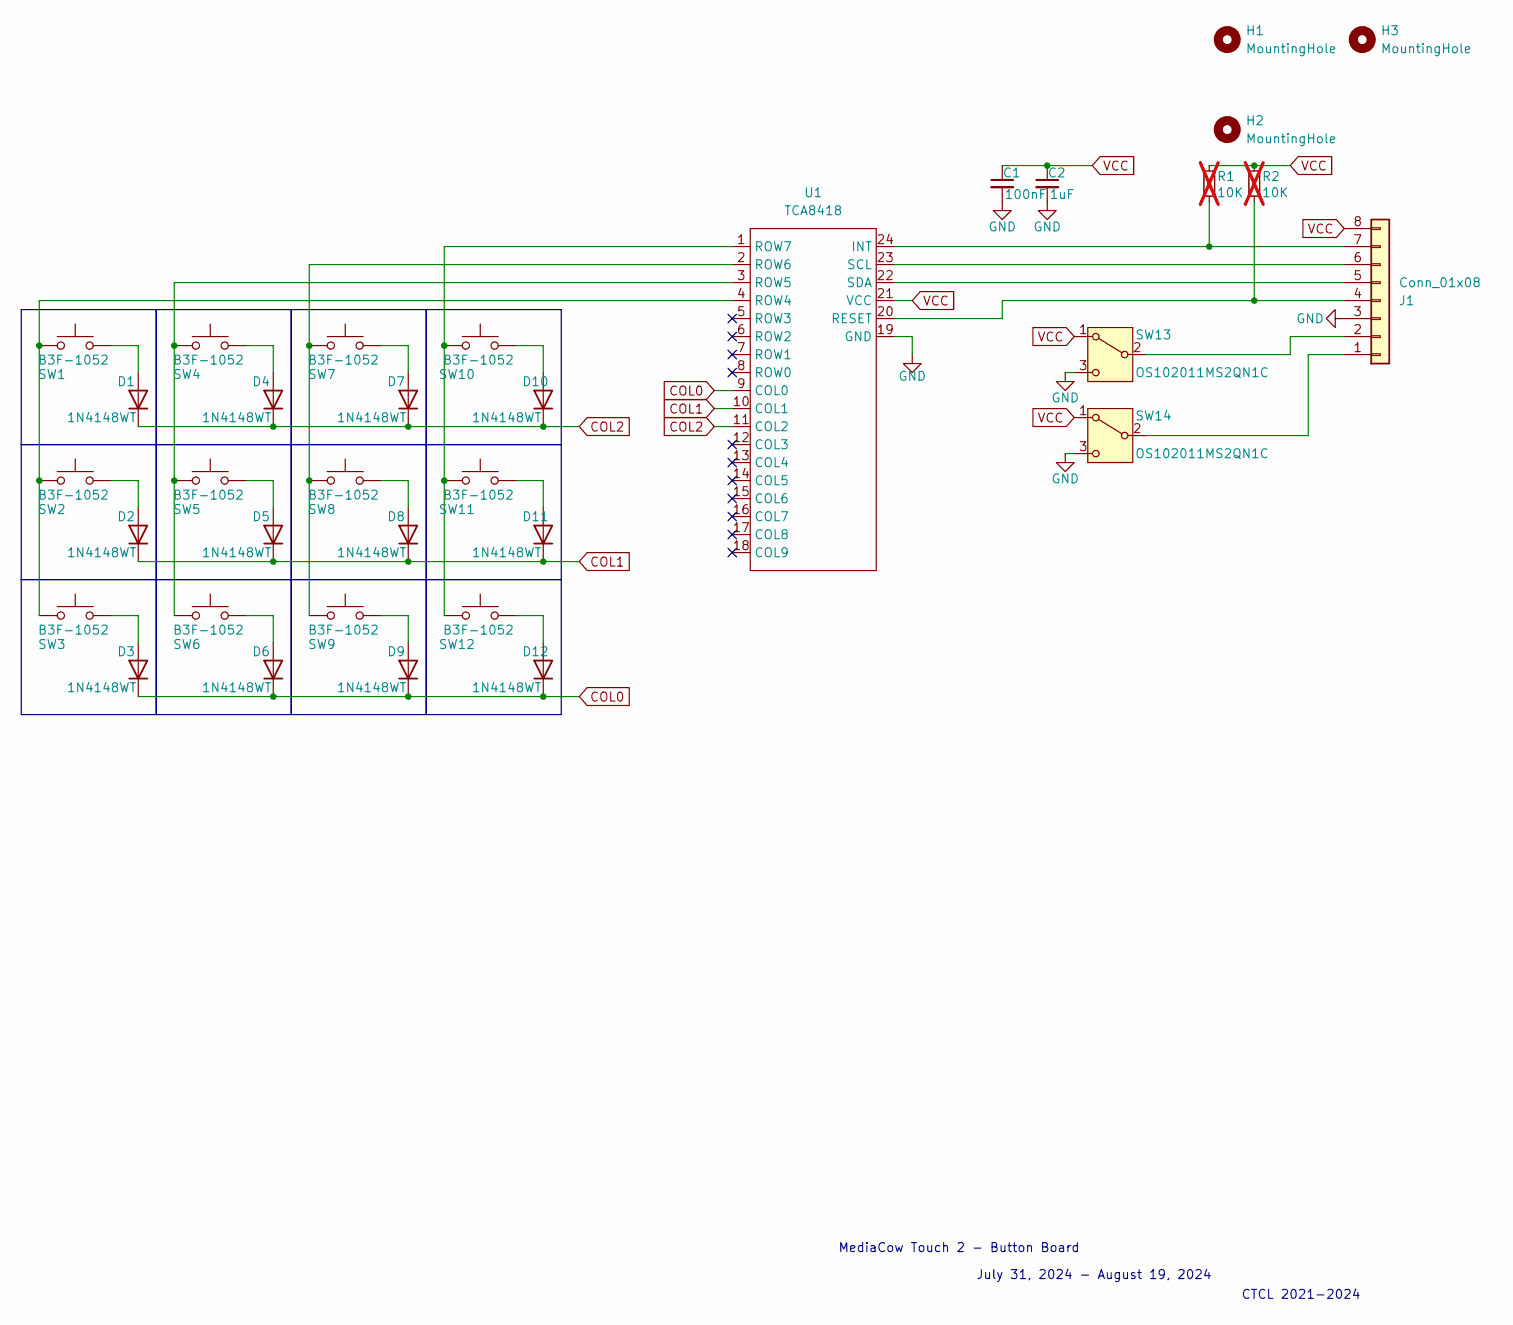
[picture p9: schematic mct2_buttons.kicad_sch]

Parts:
C1: 100nF; C_0603_1608Metric
C2: 1uF; C_0603_1608Metric
D1, D2, D3, D4, D5, D6, D7, D8, D9, D10, D11, D12: 1N4148WT; D_SOD-523
H1, H2, H3: MountingHole; MountingHole_2.2mm_M2_Pad
J1: Conn_01x08; Molex_200528-0080_1x08-1MP_P1.00mm_Horizontal
R1, R2: 10K; R_0603_1608Metric; not fitted
SW1, SW2, SW3, SW4, SW5, SW6, SW7, SW8, SW9, SW10, SW11, SW12: B3F-1052; SW_TH_Tactile_Omron_B3F-10xx_center
SW13, SW14: OS102011MS2QN1C; SW_Slide_SPDT_Straight_CK_OS102011MS2Q_center
U1: TCA8418; Texas_RTW_WQFN-24-1EP_4x4mm_P0.5mm_EP2.7x2.7mm

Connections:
COL0: D3.1 (K), D6.1 (K), D9.1 (K), D12.1 (K), U1.9 (COL0)
COL1: D2.1 (K), D5.1 (K), D8.1 (K), D11.1 (K), U1.10 (COL1)
COL2: D1.1 (K), D4.1 (K), D7.1 (K), D10.1 (K), U1.11 (COL2)
GND: C1.2, C2.2, J1.3, SW13.3 (C), SW14.3 (C), U1.19 (GND)
unnamed: D1.2 (A), SW1.2
unnamed: D2.2 (A), SW2.2
unnamed: D3.2 (A), SW3.2
unnamed: D4.2 (A), SW4.2
unnamed: D5.2 (A), SW5.2
unnamed: D6.2 (A), SW6.2
unnamed: D7.2 (A), SW7.2
unnamed: D8.2 (A), SW8.2
unnamed: D9.2 (A), SW9.2
unnamed: D10.2 (A), SW10.2
unnamed: D11.2 (A), SW11.2
unnamed: D12.2 (A), SW12.2
unnamed: J1.1, SW14.2 (B)
unnamed: J1.2, SW13.2 (B)
unnamed: J1.4, R2.2, U1.20 (RESET)
unnamed: J1.5, U1.22 (SDA)
unnamed: J1.6, U1.23 (SCL)
unnamed: J1.7, R1.2, U1.24 (INT)
unnamed: SW1.1, SW2.1, SW3.1, U1.4 (ROW4)
unnamed: SW4.1, SW5.1, SW6.1, U1.3 (ROW5)
unnamed: SW7.1, SW8.1, SW9.1, U1.2 (ROW6)
unnamed: SW10.1, SW11.1, SW12.1, U1.1 (ROW7)
VCC: C1.1, C2.1, J1.8, R1.1, R2.1, SW13.1 (A), SW14.1 (A), U1.21 (VCC)

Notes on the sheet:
July 31, 2024 - August 19, 2024
CTCL 2021-2024
MediaCow Touch 2 - Button Board

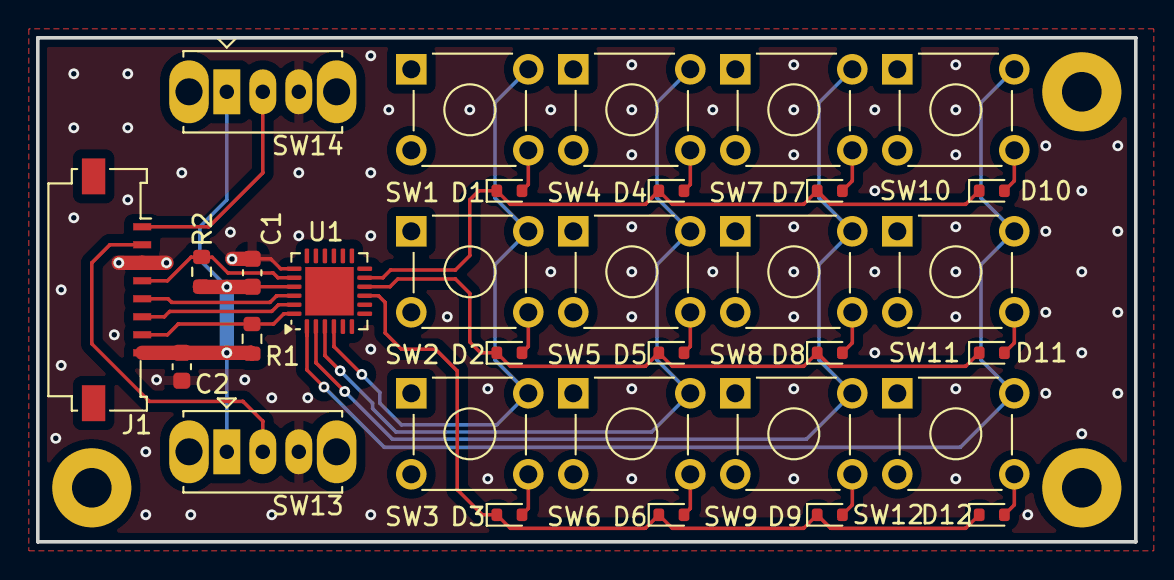
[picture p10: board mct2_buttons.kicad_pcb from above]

Board: 2 copper layers, 61.0 x 28.0 mm, 35 parts (0 on the bottom side), 27 nets.

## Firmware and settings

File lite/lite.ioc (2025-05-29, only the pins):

Mcu.UserName=STM32L071V8Tx
PA10.Signal=I2C1_SDA
PA9.Signal=I2C1_SCL
PB10.Signal=I2C2_SCL
PB11.Signal=I2C2_SDA
PB2.Signal=I2C3_SMBA
PB5.Signal=I2C1_SMBA
PC0.Signal=I2C3_SCL
PC1.Signal=I2C3_SDA
PH0-OSC_IN.Signal=RCC_OSC_IN
PH1-OSC_OUT.Signal=RCC_OSC_OUT

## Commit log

2024-07-07 July 7 2024
    [mct2.kicad_sch, mct2_case.scad]
2024-07-11 block diagram and schematic update
    [mct2.kicad_sch, mct2_io.kicad_sch]
2024-07-12 figuring out USB3
    [mct2_io.kicad_sch]
2024-07-19 diagram updates, case update
    [mct2.kicad_pcb, mct2.kicad_sch, mct2_case.scad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]
2024-07-19 schem update July 19 2024
    [mct2.kicad_sch, mct2_io.kicad_sch, mct2_power.kicad_sch]
2024-07-21 July 21, 2024
    [mct2.kicad_sch, mct2_io.kicad_sch, mct2_power.kicad_sch]
2024-07-23 July 23, 2024
    [mct2.kicad_sch, mct2_io.kicad_sch, mct2_power.kicad_sch]
2024-07-25 Schematic updates July 25, 2024
    [mct2_io.kicad_sch, mct2_power.kicad_sch]
2024-07-25 schem update 2 July 25, 2024
    [mct2_power.kicad_sch]
2024-07-28 July 27, 2024
    [mct2_case.scad, mct2_io.kicad_sch, mct2_power.kicad_sch]
2024-08-01 Aug 1, 2024
    [mct2.kicad_sch, mct2_buttons.kicad_pcb, mct2_buttons.kicad_sch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]
2024-08-02 Aug 2, 2024
    [mct2_ec.kicad_sch, mct2_power.kicad_sch]
2024-08-03 Aug 3, 2024
    [mct2_buttons.kicad_pcb, mct2_buttons.kicad_sch, mct2_ec.kicad_sch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]
2024-08-07 Aug 7, 2024 stuff in case I don't work on this before going to FMB
    [mct2_buttons.kicad_pcb, mct2_io.kicad_sch, mct2_power.kicad_sch]
2024-08-11 Aug 10, 2024
    [mct2.kicad_sch, mct2_cad.FCStd, mct2_ec.kicad_sch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]
2024-08-11 Aug 11, 2024 1
    [mct2_ec.kicad_sch, mct2_power.kicad_sch]
2024-08-11 Aug 11, 2024 2
    [mct2.kicad_sch, mct2_ec.kicad_sch, mct2_io.kicad_sch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]
2024-08-13 Aug 13, 2024
    [mct2.kicad_sch, mct2_ec.kicad_sch, mct2_io.kicad_sch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]
2024-08-16 Aug 14, 2024 old stuff
    [mct2.kicad_sch, mct2_io.kicad_sch]
2024-08-17 Aug 17, 2024
    [mct2.kicad_sch, mct2_io.kicad_sch, mct2_power.kicad_sch]
2024-08-18 Aug 17, 2024 2
    [mct2.kicad_sch, mct2_io.kicad_sch]
2024-08-19 Aug 19, 2024
    [mct2.kicad_sch, mct2_buttons.kicad_sch, mct2_ec.kicad_sch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]
2024-08-21 Aug 21, 2024 1
    [mct2.kicad_sch, mct2_ec.kicad_sch, mct2_io.kicad_sch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]
2024-08-22 Aug 22, 2024 1
    [mct2_ec.kicad_sch, mct2_io.kicad_sch, mct2_power.kicad_sch]
2024-08-26 Aug 26, 2024
    [mct2_io.kicad_sch, mct2_power.kicad_sch]
2024-08-28 Aug 28, 2024
    [mct2_power.kicad_sch]
2024-08-31 Aug 31, 2024
    [mct2.kicad_sch, mct2_ec.kicad_sch, mct2_io.kicad_sch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]
2024-09-04 Sep 4, 2024 1
    [mct2.kicad_sch, mct2_ec.kicad_sch]
2024-09-04 Sep 4, 2024 2
    [mct2.kicad_sch, mct2_io.kicad_sch, mct2_power.kicad_sch]
2024-09-05 Sep 5, 2024 1
    [mct2_ec.kicad_sch, mct2_io.kicad_sch]
2024-09-05 Sep 5, 2024 2
    [mct2.kicad_sch, mct2_ec.kicad_sch, mct2_io.kicad_sch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]
2024-09-12 Sep 12, 2024 2
    [mct2_ec.kicad_sch, mct2_io.kicad_sch, mct2_power.kicad_sch]
2024-09-17 Sep 17, 2024 1
    [mct2_ec.kicad_sch]
2024-11-29 begin refactoring
    [mct2.kicad_pcb, mct2.kicad_sch, mct2_buttons.kicad_pcb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]
2024-12-01 Dec 1, 2024 video switch PCB idea
2025-01-08 20250107-1 Type-C controller ideas and more backgrounds
    [base.dxf, display_cover.dxf, display_mount.dxf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]
2025-01-27 20250127-1 case designs
    [base.dxf, display_mount.dxf, mct2_case_old.scad]
2025-02-20 20250220-1 Add GOWIN FPGA symbol
    [mct2_buttons.kicad_pcb, mct2_buttons.kicad_sch]
2025-04-26 20250426-1 Remove current codename
    [mct2_lite.kicad_sch, mct2_lite_io.kicad_sch, mct2_lite_power.kicad_sch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]
2025-07-12 20250712-1 mv docs from website to repo
    [mct2_lite.kicad_sch, mct2_lite_io.kicad_sch, mct2_lite_power.kicad_sch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]
